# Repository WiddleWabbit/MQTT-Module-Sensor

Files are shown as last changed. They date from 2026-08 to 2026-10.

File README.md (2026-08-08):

# MQTT Module - Current Sensors

*Currently In Testing - Not Yet Tested*

This module is a plug-in board for the [MQTT Modular Controller Board](https://github.com/WiddleWabbit/MQTT-ModularControllerBoard). It powers and reads up to three 4-20mA current sensors with high-side sensing at approximately 25V, providing 15-bit resolution measurements.

## Features

- Supports up to 3 x 4-20mA sensors (high-side sensing)
- 15-bit resolution via ADS1115 ADC
- On-board ~25V boost converter from 12V input (TPS61170)
- ATmega328PB microcontroller for local control and communication
- Precision 0.1% shunt resistors with low temperature coefficient (25ppm/°C)
- Basic short-circuit protection using PTCs and TVS diodes
- I2C communication with motherboard and internal ADC

## Architecture

The module is built around an **ATmega328PB-A** microcontroller. It interfaces with the motherboard via I2C (SDA on PE1, SCL on PE0) and uses a dedicated I2C bus for the **ADS1115** ADC (base address 0x48, SDA on PC4, SCL on PC5).

### Power
- Utilises 12V input from motherboard, boosted to ~25V using TI TPS61170 (WEBENCH design) with shielded inductor for reduced EMI
- Powers up to three 4-20mA sensors using this 25V.
- Also utilises the 3.3V from the motherboard.
- Maximum 25V current draw should be less than 200mA.
- Maximum 3.3V current draw should be less than 200mA.

### Sensor Interface
- TP5551 OpAmps in servo configuration for accurate current-to-voltage conversion
- 1.5uF capacitors for signal smoothing
- 0.1% precision shunt resistors with a low 25ppm/°C

### Protection
- PTC resettable fuses on sensors trigger at ~150mA
- TVS diodes for overvoltage clamping (trigger at 13V, clamp to 21.5V)
- Shunt rated for 21.5V for five seconds

### Pinout and Connections
- **Motherboard I2C**: SDA (PE1), SCL (PE0)
- **Internal ADC I2C**: SDA (PC4), SCL (PC5)
- **SNS pin** (motherboard sense): PD4
- **General use modular pin**: PD3
- **ISP Programming Header** (2x3, left to right, top to bottom): MISO, VCC, SCK, MOSI, RESET, GND

## Setup and Build

**Firmware**: Not yet implemented. TBA.

**Programming**:
1. Use the 2x3 ISP header to program the ATmega328PB.
2. Connect to an ISP programmer (e.g., USBasp or Arduino as ISP).
3. Firmware will handle sensor readings, ADC configuration, and I2C communication with the motherboard.

**Assembly**:
- Populate the board per the KiCad project files.
- Ensure proper orientation when plugging into the motherboard slots.

## License

This documentation is part of MQTT-Module-Sensor Project and is licensed under the CERN Open Hardware Licence Version 2 - Permissive (CERN-OHL-P-2.0). 
You may redistribute and modify this documentation under the terms of the CERN-OHL-P-2.0. 
This documentation is distributed WITHOUT ANY EXPRESS OR IMPLIED WARRANTY, INCLUDING OF MERCHANTABILITY, SATISFACTORY QUALITY AND FITNESS FOR A PARTICULAR PURPOSE. See the CERN-OHL-P-2.0 for applicable conditions.

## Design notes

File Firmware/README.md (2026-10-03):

# Sensor module firmware

How the firmware runs, and the lookup pages, are in [docs/home.md](docs/home.md).

# Getting Started 

```pio run -e fuses_bootloader -t fuses```
Burn the fuses

```pio run -e Upload_ISP -t upload```
Upload

# AVR Dude

### Burning Fuses

#### Clock Speed

Use this command to read the current fuses.
```avrdude -C "%USERPROFILE%\.platformio\packages\tool-avrdude\avrdude.conf" -p atmega328pb -P COM3 -b 19200 -c stk500v1 -v -U lfuse:r:-:h -U hfuse:r:-:h -U efuse:r:-:h```

Use this command to write the fuses
```avrdude -C "%USERPROFILE%\.platformio\packages\tool-avrdude\avrdude.conf" -p atmega328pb -P COM3 -b 19200 -c stk500v1 -U lfuse:w:0xE2:m```

0xE2 Should be 11100010, which should set flag 7 (CKDIV8) to 0, stopping the device dividing the system block by 8. This may need to be modified based on what is read, hence the read command first.

#### Brown Out Detection

Use this command to read the fuse.
```avrdude -c stk500v1 -P COM3 -b 19200 -p m328pb -U efuse:r:-:h```

Use this command to write the fuse to 3.3V board (2.7V Brown Out Detection).
```avrdude -c stk500v1 -P COM3 -b 19200 -p m328pb -U efuse:w:0xFD:m```

Needs to be read in firmware and cleared as required. Holds the device in reset if it runs out of power.

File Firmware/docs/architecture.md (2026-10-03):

# Firmware architecture

[Home](home.md) · Reference: [Architecture](reference/architecture.md)

## Summary

This firmware runs on the ATmega328PB sensor daughterboard. The ESP32
motherboard is the I2C master on TWI1. This board is the master on
TWI0, where it reads three 4-20 mA inputs through an ADS1115. Plugging
it in is enough for the motherboard to assign an address and identify
a sensor module with three inputs.

`src/main.cpp` is the composition root. It owns the pin constants and
the product settings, constructs the adapters, the scan, and the link,
and calls `update()` on the scan and the link.

## Where it sits

Global construction runs before `setup()`. `ModuleLink` registers its
master-write handler there. The slave stays off until `loop()` sees
MOD low.

The motherboard bus is schematic I2C0. On this chip that is TWI1,
Arduino `Wire1`. The ADC bus is schematic I2C1, TWI0 on PC4 and PC5,
Arduino `Wire`. The ADS1115 is the only device on that bus.

## What it creates

```text
main.cpp
  AvrTwi1Slave     TWI1 adapter for IModuleSlavePort
  AvrAds1115       TWI0 adapter for IAds1115
  SensorInputs     round-robin scan and the sample cache
  ModuleLink       MOD gate, frames, and replies
```

`main.cpp` passes `MODULE_TYPE` and `FIRMWARE_VERSION` into the link,
and passes the ADS1115 address, gain, rate, input count, and connected
threshold into the scan. Pin numbers stay in `main.cpp`.

`lib/Interfaces/` holds `IModuleSlavePort` and the copied
`ModuleProtocol.h`. `lib/Drivers/` holds the AVR adapter. `lib/Logic/`
holds the link. Desktop fakes live in `test/test_desktop/fakes/`.

## One update

`setup()` drives `SNS_PIN` low so the motherboard sense line says the
module is seated, and holds `MOD_PIN` as an input with pull-up.

```mermaid
flowchart TD
  loop["loop()"] --> scan["sensorInputs.update()"]
  scan --> read["digitalRead MOD_PIN"]
  read --> upd["moduleLink.update(modIsLow)"]
```

`loop()` does not block, so a low MOD is seen inside `kModGateMaxMs`.
Each sensor pass makes one ADC-driver call and returns. While the
module has no address, MOD low enables `0x0A` and MOD high disables
it. After a valid `SET_ADDRESS`, the link keeps that address when MOD
rises.

## What is stored, and who reads it

Each pass reads `MOD_PIN` and passes that level to the link. The
motherboard reads the sense line, which `SNS_PIN` holds low.

The link stores the address and whether it has been assigned. The TWI1
adapter stores the reply the host clocks out. The scan stores the
latest ADS1115 counts. Those stores are on the
[module link](module-link.md), [sensor inputs](sensor-inputs.md),
[slave port](slave-port.md), and [ADC port](adc-port.md) pages.

## See also

- [Architecture reference](reference/architecture.md) — pins, the pass, the image build.
- [Module link](module-link.md)
- [Sensor inputs](sensor-inputs.md)
- [Slave port](slave-port.md)
- [ADC port](adc-port.md)

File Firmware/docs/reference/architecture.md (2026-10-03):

# Architecture reference

[Home](../home.md) · Guide: [Architecture](../architecture.md)

## Purpose

`src/main.cpp` wires this daughterboard. It owns the pins and the
product settings, constructs the adapters, the scan, and the link, and
calls the scan and the link once per pass.

## Classes

`setup` drives `SNS_PIN` and configures `MOD_PIN`. `loop` calls
`SensorInputs::update`, reads `MOD_PIN`, and calls `ModuleLink::update`.
The objects are `moduleSlave` (`AvrTwi1Slave`), `ads` (`AvrAds1115`),
`sensorInputs` (`SensorInputs`), and `moduleLink` (`ModuleLink`).

## States

The sketch has no mode of its own. Listening, assignment, and replies
are the link's states, on the [module link reference](module-link.md).
The scan's phases are on the
[sensor inputs reference](sensor-inputs.md).

## Sequences

1. Construction registers the master-write handler. The slave stays off.
2. `setup` sets `SNS_PIN` as an output driven low, and `MOD_PIN` as an input with pull-up.
3. Each `loop` advances the scan one driver call, reads `MOD_PIN`, and calls the link. Both calls return without waiting.

The host holds MOD low for `kModGateMaxMs` (5 ms). Because `loop` does
not block, the unconfigured address is enabled on the pass that sees
MOD low.

## Errors

Protocol status bytes come from the link. A handler that runs in the
TWI interrupt finishes inside `kClockStretchMaxMs` (40 ms). Both limits
are in `ModuleProtocol.h`.

## Configuration

Declared in `src/main.cpp`.

| Constant | Value | Port | Role |
| --- | --- | --- | --- |
| `SCL_PIN` | 23 | PE0 | Motherboard SCL, TWI1 |
| `SDA_PIN` | 24 | PE1 | Motherboard SDA, TWI1 |
| `MOD_PIN` | 3 | PD3 | Enumeration select, input pull-up |
| `SNS_PIN` | 4 | PD4 | Seated detect, driven low |
| `ADC_SDA_PIN` | 18 | PC4 | ADS1115 SDA, TWI0. `Wire` takes no pin argument |
| `ADC_SCL_PIN` | 19 | PC5 | ADS1115 SCL, TWI0. `Wire` takes no pin argument |
| `MODULE_TYPE` | `kTypeSensorModule` | | Reported by `GET_IDENTITY` |
| `FIRMWARE_VERSION` | 1 | | Reported by `GET_IDENTITY` |
| `ADS1115_ADDRESS` | `0x48` | | ADDR strapped to GND |
| `SENSOR_COUNT` | 3 | | Inputs reported by `GET_SENSOR_COUNT` |
| `SENSOR_CONNECTED_MIN_COUNTS` | 2400 | | Connected at or above this raw count |

`ads` is constructed with `AvrAds1115::kGainOne` (`0x0200`, ±4.096 V)
and `AvrAds1115::kRate860Sps` (`0x00E0`).

`kTypeSensorModule` is `0x0200` in `ModuleProtocol.h`. MiniCore's names
for the TWI1 pins are reversed. That constraint is on the
[slave port reference](slave-port.md).

The image is an ATmega328PB at 8 MHz from the internal oscillator.
`Upload_ISP` programs it with stk500v1 at 19200 on COM3.
`fuses_bootloader` sets no bootloader, brown-out 2.7 V, and EEPROM
save. The avrdude lines are in the firmware `README.md`.

## Tests

Desktop cases and the command that runs them are on the
[module link reference](module-link.md) and the
[sensor inputs reference](sensor-inputs.md).

The image build is:

```text
pio run -e Upload_ISP
```

That environment does not run the desktop tests. The TWI interrupt
path and the ADS1115 bus are not executed on the desktop.

## Source

- `src/main.cpp`
- `platformio.ini`

Sources in a library root are compiled when one of its headers is
included. `platformio.ini` does not list `lib_deps` for that reason.

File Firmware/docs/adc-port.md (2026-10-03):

# ADC port

[Home](home.md) · Reference: [ADC port](reference/adc-port.md)

## Summary

`IAds1115` is the seam between the sensor scan and the ADS1115.
`AvrAds1115` is the TWI0 adapter. It uses the Adafruit ADS1X15 library
on `Wire`. Desktop tests use `FakeAds1115`.

## Where it sits

`main.cpp` constructs `AvrAds1115` with `ADS1115_ADDRESS`,
`AvrAds1115::kGainOne`, and `AvrAds1115::kRate860Sps`, and passes it to
`SensorInputs`. The sketch does not call the driver. `SensorInputs`
does.

## What it creates

```text
IAds1115
  AvrAds1115      Adafruit ADS1115 on Wire, TWI0
  FakeAds1115     records calls and returns scripted counts
```

One driver instance owns the chip. The Adafruit object is created on
the first `begin()`, inside the driver translation unit.

## One update

The sketch does not call the driver. One scan step is one of these
calls.

```text
begin()              Wire.begin(), then probe the address
startSingleEnded()   single-shot conversion on one input
conversionReady()    read the OS bit
readCounts()         read the conversion register
```

## What is stored, and who reads it

The driver stores the address, the gain, the data rate, and whether
`begin()` succeeded. The conversion result lives in the ADS1115 until
`readCounts()`. `SensorInputs` copies it into the cache.

`ADC_SDA_PIN` and `ADC_SCL_PIN` name PC4 and PC5. `Wire` takes no pin
argument, because TWI0's pins are fixed.

## See also

- [ADC port reference](reference/adc-port.md) — gain, the OS bit, what the fake records.
- [Sensor inputs](sensor-inputs.md)
- [Architecture](architecture.md)

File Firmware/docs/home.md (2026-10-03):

# Sensor module firmware

The sensor daughter is one module. `src/main.cpp` constructs the two
bus adapters, the sensor scan, and the link. It calls `update()` on
the scan and on the link. It does not run the steps inside either one.

## How the firmware runs

Each of these is a short page: what that part creates, and what one
pass does.

1. [Architecture](architecture.md) — the loop, and who owns whom.
2. [Module link](module-link.md) — the MOD gate, then one master write.
3. [Sensor inputs](sensor-inputs.md) — one ADS1115 step, then the cache.
4. [Slave port](slave-port.md) — TWI1 on the AVR, and the desktop fake.
5. [ADC port](adc-port.md) — TWI0 to the ADS1115, and the desktop fake.

## When you need a byte, a state, or a test

The [reference index](reference/index.md) is the lookup. Each page
there has the states, the sequences, the errors, and the desktop test
that covers them.

## Wire contract

`lib/Interfaces/ModuleProtocol.h` is the copy of the motherboard
header. Frame layout, CRC-8/SMBus, command bytes, `kModGateMaxMs`, and
`kClockStretchMaxMs` live there. If a page in this tree and that header
disagree, the header wins. Change the motherboard header, then copy it
here.

This tree documents the slave. The motherboard's master sequences stay
in the motherboard firmware.

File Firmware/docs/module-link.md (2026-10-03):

# Module link

[Home](home.md) · Reference: [Module link](reference/module-link.md)

## Summary

`ModuleLink` is the slave side of the motherboard module protocol for
this sensor board. It listens at `0x0A` only while MOD is low, then
keeps the assigned address. It reports the type and firmware version
supplied at construction, protocol version 1, and the sensor count and
samples held by `SensorInputs`.

The module includes no Arduino headers.

## Where it sits

`main.cpp` constructs it with `AvrTwi1Slave`, `SensorInputs`,
`MODULE_TYPE` (`kTypeSensorModule`), and `FIRMWARE_VERSION`. `loop()`
calls `update(modIsLow)`. A master write arrives through the handler
the constructor registered, from the TWI receive callback or from
`FakeModuleSlavePort::deliver`.

## What it creates

```text
ModuleLink
  IModuleSlavePort    enable, disable, setAddress, setReply
  SensorInputs        count, connected flag, raw counts
```

The link has no submodules. It cannot be copied: the port stores the
link as the write context. The link reads the sensor cache. It does
not advance the scan.

## One update

```mermaid
flowchart TD
  upd["update(modIsLow)"] --> assigned{"assigned?"}
  assigned -->|yes| keep["leave the port as it is"]
  assigned -->|no| low{"modIsLow?"}
  low -->|yes| en["enable 0x0A if it is off"]
  low -->|no| dis["disable if it is on"]
```

A master write is a separate path. The port calls the handler from the
TWI interrupt, or the fake calls it from `deliver`. Commands, rejects,
and the padded reply are in the [reference](reference/module-link.md).

## What is stored, and who reads it

`_typeId` and `_firmwareVersion` come from the constructor.
`GET_IDENTITY` reads them. `GET_SENSOR_COUNT`, `GET_SENSOR_CONNECTED`,
and `GET_SENSOR_READING` read the `SensorInputs` cache.

`_address` starts at `kUnconfiguredAddress`. `update` enables that
address while MOD is low. An accepted `SET_ADDRESS` replaces it and
sets `_assigned`. `_enabled` records whether the port is listening.
Once `_assigned` is set, `update` leaves the port alone.

The link does not keep the last reply. `setReply` copies it into the
port before the handler returns. The host reads that copy.

## See also

- [Module link reference](reference/module-link.md) — states, commands, errors, tests.
- [Sensor inputs](sensor-inputs.md)
- [Slave port](slave-port.md)
- [Architecture](architecture.md)

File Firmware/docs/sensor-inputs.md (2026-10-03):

# Sensor inputs

[Home](home.md) · Reference: [Sensor inputs](reference/sensor-inputs.md)

## Summary

`SensorInputs` scans the ADS1115 and keeps the latest counts for each
input. `ModuleLink` reads that cache when the motherboard asks for a
count, a presence, or a reading. The scan runs from `loop()`. The TWI1
handler does not talk to the ADC.

## Where it sits

`main.cpp` constructs it with `AvrAds1115`, `SENSOR_COUNT`, and
`SENSOR_CONNECTED_MIN_COUNTS`. `loop()` calls `update()` and then
`moduleLink.update()`. The link does not call `update()`.

## What it creates

```text
SensorInputs
  IAds1115    begin, start, poll, read
```

On this board the count is 3. Index 0 is Sens1 on AIN0, index 1 is
Sens2 on AIN1, and index 2 is Sens3 on AIN2. AIN3 is unconnected.

## One update

```mermaid
flowchart TD
  upd["update()"] --> none{"count is 0?"}
  none -->|yes| stop["return"]
  none -->|no| begun{"begun?"}
  begun -->|no| begin["begin() and return"]
  begun -->|yes| st{"phase?"}
  st -->|Starting| start["startSingleEnded(channel)"]
  st -->|Waiting| rdy{"conversionReady()?"}
  rdy -->|no| wait["return"]
  rdy -->|yes| mark["remember that the result is ready"]
  st -->|Reading| store["store counts and the connected flag"]
  store --> next["next channel, then Starting"]
```

One `update()` makes one driver call. The first sample is a begin, a
start, a ready poll, and a read. Each later sample is a start, a poll,
and a read.

## What is stored, and who reads it

The constructor stores the count and the connected threshold.
`update()` stores the latest counts and a connected flag for each
input. The flag is set when the counts are at or above
`SENSOR_CONNECTED_MIN_COUNTS`.

The valid flag for that input is cleared before those bytes are
written and set after them. `ModuleLink` reads an input from the TWI1
handler only while its flag is set. Until the first stored conversion,
the link replies `Busy`.

## See also

- [Sensor inputs reference](reference/sensor-inputs.md) — phases, the threshold, tests.
- [ADC port](adc-port.md)
- [Module link](module-link.md)
- [Architecture](architecture.md)

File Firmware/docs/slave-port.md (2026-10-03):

# Slave port

[Home](home.md) · Reference: [Slave port](reference/slave-port.md)

## Summary

`IModuleSlavePort` is the seam between the link and the bus.
`AvrTwi1Slave` is the TWI1 adapter. Desktop tests use
`FakeModuleSlavePort`. The fake's `deliver` calls the same handler the
driver's receive callback calls.

## Where it sits

`main.cpp` constructs `AvrTwi1Slave` and passes it to `ModuleLink`. The
link calls `enable`, `disable`, `setAddress`, and `setReply`. The
driver calls the link back on a master write. Tests construct the fake
in place of the driver.

## What it creates

```text
IModuleSlavePort
  AvrTwi1Slave          Wire1 on TWI1
  FakeModuleSlavePort   records calls
```

Wire's callbacks are plain function pointers, so one driver instance
is the active slave. That instance attaches one protocol handler.

## One update

The sketch does not call the driver. One transaction is a master
write, then the repeated-start read.

```mermaid
flowchart TD
  rx["onReceive"] --> hand["write handler"]
  hand --> reply["setReply copies the frame"]
  reply --> tx["onRequest clocks the copy out"]
```

`setAddress` writes `TWAR1` from the stop callback and leaves the bus
up. `disable` calls `Wire1.end()`.

## What is stored, and who reads it

The driver keeps the handler, the reply bytes, and whether TWI1 is
enabled. The host clocks the reply out on the next read. `TWAR1` is
the address the peripheral acknowledges. The fake keeps the same calls
so a test can read them.

`SCL_PIN` and `SDA_PIN` name the motherboard-bus pins. `Wire1` takes
no pin argument, because TWI1's pins are fixed.

## See also

- [Slave port reference](reference/slave-port.md) — `TWAR1`, pin names, what the fake records.
- [Module link](module-link.md)
- [Architecture](architecture.md)

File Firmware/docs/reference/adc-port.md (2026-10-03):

# ADC port reference

[Home](../home.md) · Guide: [ADC port](../adc-port.md)

## Purpose

One ADC port, two adapters. The scan starts a conversion, polls it,
and reads the counts. `AvrAds1115` does that on TWI0 through Adafruit
ADS1X15. `FakeAds1115` records the same calls.

## Classes

`IAds1115`:

| Method | Role |
| --- | --- |
| `begin()` | Start the bus and probe the chip |
| `startSingleEnded(channel)` | Start one single-shot conversion. Channel 0 is AIN0 |
| `conversionReady()` | True when the OS bit says the conversion is done |
| `readCounts()` | Signed result of the last conversion |

`AvrAds1115(address7bit, gain, dataRate)` stores those settings and
leaves the bus idle. `kGainOne` is `0x0200` (±4.096 V, 125 uV per
count). `kRate860Sps` is `0x00E0`. Copy and assignment are deleted.

`FakeAds1115` records `begin`, `startSingleEnded`, `conversionReady`,
and `readCounts`. `readCounts` returns `counts[lastChannel]`.

## States

The driver starts with the bus idle. `begin()` sets the gain and the
data rate, calls `Wire.begin()`, and probes the address. A gain other
than `kGainOne`, or a rate other than `kRate860Sps`, returns false and
does not mark the bus ready. Later calls return false, or 0 counts,
until a `begin()` succeeds.

## Sequences

`startSingleEnded` rejects a channel above 3. Adafruit's
`startADCReading` writes the config register and both threshold
registers. The threshold writes arm ALERT/RDY. That pin is
unconnected on this board. `conversionReady()` polls the config
register OS bit.

`Wire.begin()` turns on the internal pull-ups on PC4 and PC5, in
parallel with the board's pull-ups. `ADC_SDA_PIN` is 18 and
`ADC_SCL_PIN` is 19. `Wire` takes no pin arguments.

The ADS1115 address is `ADS1115_ADDRESS` (`0x48`). ADDR is strapped
to GND.

## Errors

`begin()` false means the chip did not acknowledge, or the gain or
rate was refused. `startSingleEnded` false means the bus is not ready
or the channel is above 3. `readCounts()` before a successful `begin()`
returns 0.

Adafruit's start and register reads do not report a bus error of
their own. A chip that stops acknowledging after `begin()` leaves
`conversionReady()` false, so the scan stays on that channel.

## Configuration

Passed from `main.cpp`: address `0x48`, `kGainOne`, `kRate860Sps`.
Single-ended readings use the positive half of the code, 0..32767.
The connected threshold is a `SensorInputs` setting, on the
[sensor inputs reference](sensor-inputs.md).

## Tests

There is no separate driver test. The sensor-input tests drive
`FakeAds1115`. The cases are on the
[sensor inputs reference](sensor-inputs.md). The TWI0 path is not
executed on the desktop. `pio run -e Upload_ISP` compiles
`AvrAds1115`.

## Source

- `lib/Interfaces/IAds1115.h`
- `lib/Drivers/AvrAds1115.h`
- `lib/Drivers/AvrAds1115.cpp`
- `test/test_desktop/fakes/FakeAds1115.h`

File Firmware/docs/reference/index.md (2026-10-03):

# Reference

[Home](../home.md)

These pages are the lookup: states, bytes, errors, and the desktop
test that covers them. The short pages one level up say who creates
what and what one pass does.

- [Architecture](architecture.md) — pins, the pass, and the image build.
- [Module link](module-link.md) — MOD gate, commands, and the desktop tests.
- [Sensor inputs](sensor-inputs.md) — the scan, the cache, and the threshold.
- [Slave port](slave-port.md) — TWI1, `TWAR1`, and the fake.
- [ADC port](adc-port.md) — TWI0, GAIN_ONE, and the fake.

The wire constants are `lib/Interfaces/ModuleProtocol.h`. Master
sequences are not in this tree.

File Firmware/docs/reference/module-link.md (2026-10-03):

# Module link reference

[Home](../home.md) · Guide: [Module link](../module-link.md)

## Purpose

Slave side of the module protocol for one sensor module. It accepts an
address while MOD is low, then identifies as the type and firmware
version it was given, with protocol version 1. Sensor commands read
the `SensorInputs` cache.

Frame layout, CRC-8/SMBus, and command bytes are in
`lib/Interfaces/ModuleProtocol.h`. If this page and that header
disagree, the header wins.

## Classes

`ModuleLink(IModuleSlavePort& port, SensorInputs& sensors, uint16_t typeId, uint16_t firmwareVersion)`
binds the port and the sensor cache, and registers the master-write
handler. The slave stays off. Copy and assignment are deleted.

`update(bool modIsLow)` is the call `loop` makes.

The port methods the link uses are `enable`, `disable`, `setAddress`,
`setReply`, and `setMasterWriteHandler`. `setReply` copies the bytes
before it returns.

## States

`kUnconfiguredAddress` is `0x0A`.

```text
boot, MOD high          slave off; stored address is 0x0A
MOD low                 enable 0x0A once
MOD low again           no second enable
MOD high, no address    disable once
SET_ADDRESS accepted    setAddress(new); stay enabled; assigned
MOD high after that     stay enabled at the new address
```

## Sequences

A master write is checked in this order:

1. A null buffer, or fewer than `kMinFrameBytes` (3), replies `BadLength`.
2. The length byte must be from 2 through `2 + kMaxPayload`, and the
   buffer size must be that length plus one. Otherwise `BadLength`.
3. CRC-8/SMBus over the bytes the length covers must match the CRC
   byte. Otherwise `BadCrc`, and the address stays as it is.
4. The command runs.

A reply is `kMaxFrameBytes` (19) long. The real frame comes first. The
rest is `0xFF`. `SET_ADDRESS`, accepted or refused as an address, queues
no reply.

On the AVR the handler runs from the TWI interrupt. On the desktop,
`FakeModuleSlavePort::deliver` calls it. It finishes inside
`kClockStretchMaxMs`.

## Commands

| Command | When | Result |
| --- | --- | --- |
| `PING` | empty payload | status `Ok`, empty payload |
| `PING` | any payload | `BadLength` |
| `GET_IDENTITY` | empty payload | type, protocol 1, firmware version |
| `GET_IDENTITY` | any payload | `BadLength` |
| `SET_ADDRESS` | enabled, not yet assigned, one payload byte, address `0x10`–`0x6F` | `setAddress`, no reply |
| `SET_ADDRESS` | payload length is not 1 | `BadLength`, no commit |
| `SET_ADDRESS` | disabled, already assigned, or address outside `0x10`–`0x6F` | no reply, no commit |
| `GET_SENSOR_COUNT` | empty payload | status `Ok`, the cache's count |
| `GET_SENSOR_COUNT` | any payload | `BadLength` |
| `GET_SENSOR_CONNECTED` | one index byte, index inside the count, sample stored | `Ok`, index, connected `0` or `1` |
| `GET_SENSOR_READING` | one index byte, index inside the count, sample stored | `Ok`, index, connected, raw counts as big-endian `int32` |
| `GET_SENSOR_CONNECTED`, `GET_SENSOR_READING` | index inside the count, no sample yet | `Busy` |
| `GET_SENSOR_CONNECTED`, `GET_SENSOR_READING` | payload length is not 1, or index at or above the count | `BadLength` |
| any other command, including `ECHO` | | `UnknownCmd` |

Identity payload, big-endian: type high, type low, `kProtocolVersion`,
firmware high, firmware low. `kIdentityPayloadLen` is 5.

`SET_ADDRESS` commits from the stop callback, before the motherboard
releases MOD. A later `SET_ADDRESS` is ignored. `0x00` is not an
assignable address. `isAssignableAddress` accepts `kMinAssignedAddress`
through `kMaxAssignedAddress`.

## Errors

| Status | Constant | When |
| --- | --- | --- |
| `Ok` | `kStatusOk` (`0x00`) | PING, identity, sensor count, or a stored sample |
| `BadCrc` | `kStatusBadCrc` (`0x01`) | CRC byte does not match |
| `UnknownCmd` | `kStatusUnknownCmd` (`0x02`) | Command this type does not implement |
| `BadLength` | `kStatusBadLength` (`0x03`) | Short frame, length mismatch, a payload length the command rejects, or a sensor index outside the count |
| `Busy` | `kStatusBusy` (`0x04`) | Presence or reading for an input that has no stored sample yet |

A refused `SET_ADDRESS` leaves the address in place and queues no
status. The header also defines `Unsupported`. This link does not send
it. The reading payload is `kSensorReadingPayloadLen` (6): index,
connected, then the raw counts. The connected payload is
`kSensorConnectedPayloadLen` (2): index, then 0 or 1. The count
payload is one byte.

## Configuration

`typeId` and `firmwareVersion` are constructor arguments. The sketch
passes `MODULE_TYPE` and `FIRMWARE_VERSION`, listed on the
[architecture reference](architecture.md). `GET_IDENTITY` reports the
values it was given.

The sensor count, the connected threshold, and the raw counts come
from `SensorInputs`. The sketch passes `SENSOR_COUNT` and
`SENSOR_CONNECTED_MIN_COUNTS` into that object. The value on the wire
is the ADS1115 code, not a scaled current.

## Tests

`test/test_desktop/test_module_link.cpp` drives `FakeModuleSlavePort`.

| Test | Path |
| --- | --- |
| `testBootWithModHighLeavesSlaveDisabled` | MOD high at boot leaves the slave off |
| `testModLowEnablesUnconfiguredAddressAndModHighDisables` | `0x0A` follows MOD until assignment; a second call does not enable or disable again |
| `testPingReplyIsOkAndPadded` | `Ok` PING, CRC, 19-byte `0xFF` pad |
| `testIdentityReportsSensorModule` | Type `0x0200`, protocol 1, firmware 1 |
| `testSuppliedFirmwareVersion` | Identity uses the constructor values (`0x1234`, firmware 2) |
| `testSetAddressCommitsAndSurvivesModHigh` | A write while off does not commit. Then commit `0x10`, ignore `0x11`, stay on after MOD rises, and still answer PING |
| `testSetAddressRejectsBadCrcAndIllegalAddresses` | Bad CRC, `0x00`, `0x0A`, and `0x70` stay at `0x0A` |
| `testSensorCommandsReportCachedReadings` | Count 3. `Busy` before a sample. 2399 is disconnected, 2400 is connected, and -4 is disconnected. Channel 0 still reads 2399 after the others are stored |
| `testSensorCommandsRejectBadIndexAndLength` | Index 3, a short or long reading payload, a count payload, and index 0 on a count of 0 are `BadLength` |
| `testUnknownCommandAndMalformedFrames` | `ECHO`, truncated frame, extra byte, bad CRC, PING with a payload, empty `SET_ADDRESS` |
| `testEnumerationSequence` | PING, assign `0x12`, MOD high, identity, count 3 |

```text
C:\Users\Nathan\.platformio\penv\Scripts\platformio.exe test -e native
```

## Source

- `lib/Logic/ModuleLink.h`
- `lib/Logic/ModuleLink.cpp`
- `test/test_desktop/test_module_link.cpp`
- `test/test_desktop/fakes/FakeModuleSlavePort.h`

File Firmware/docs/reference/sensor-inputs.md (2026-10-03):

# Sensor inputs reference

[Home](../home.md) · Guide: [Sensor inputs](../sensor-inputs.md)

## Purpose

Scan the ADS1115 inputs and remember the latest counts. The link
reports that cache. The scan is a sequence of single driver calls so
`loop()` can still see MOD within `kModGateMaxMs`.

## Classes

`SensorInputs(IAds1115& adc, uint8_t count, int16_t connectedMinCounts)`
binds the port. Copy and assignment are deleted.

`update()` advances one step. `count()`, `hasSample(index)`,
`connected(index)`, and `counts(index)` are what the link reads. An
index outside the count has no sample, is not connected, and reads as
0 counts.

A count above `kMaxSensorsPerModule` (16) is stored as 16.

## States

```text
count 0                 update returns; the ADC is not started
not begun               the next update calls begin()
Starting                the next update calls startSingleEnded(channel)
Waiting                 the next update calls conversionReady()
Reading                 the next update calls readCounts() and stores it
```

`begin()` returning false leaves the scan not begun, so the next pass
tries again. `startSingleEnded` returning false leaves the phase at
`Starting` on the same channel. The previous sample stays. A ready
poll that is false stays in `Waiting`.

After a stored sample the channel advances by one and wraps to 0.

## Sequences

Publishing one sample clears that input's valid flag, writes the
counts and the connected flag, then sets the valid flag. The connected
flag is 1 when the signed counts are greater than or equal to
`connectedMinCounts`.

Index 0 is AIN0 (Sens1), index 1 is AIN1 (Sens2), and index 2 is AIN2
(Sens3).

## Errors

A missing chip keeps `begin()` false. No input has a sample, and the
link replies `Busy` for presence and reading. The count is still
reported.

A start that fails does not erase a sample already stored for another
input. The scan retries the channel that failed.

`counts()` for an input with no sample returns 0. The link treats
"no sample" as `Busy` rather than as a reading of 0.

## Configuration

The sketch passes `SENSOR_COUNT` (3) and
`SENSOR_CONNECTED_MIN_COUNTS` (2400). 2400 counts is 0.300 V at
GAIN_ONE, 125 uV per count, which is 2 mA through the 150 ohm shunt.
A 4 mA loop is 0.600 V, 4800 counts. A 20 mA loop is 3.000 V, 24000
counts. An open input sits near 0 V.

The gain and the sample rate are arguments to `AvrAds1115`, listed on
the [architecture reference](architecture.md).

## Tests

`test/test_desktop/test_sensor_inputs.cpp` drives `FakeAds1115`.
`test/test_desktop/test_module_link.cpp` checks the frames the link
builds from the same cache.

| Test | Path |
| --- | --- |
| `testScanStoresEachChannelThenWraps` | Channel 0, then 1, then 2, then channel 0 again. 2399 is disconnected, 2400 is connected, and a negative code stays negative. A new conversion replaces channel 0 |
| `testBeginFailureRetriesAndDoesNotStart` | `begin()` false retries and does not start a conversion |
| `testStartFailureKeepsTheLastSampleAndRetriesTheChannel` | A refused start keeps channel 0 and retries channel 1 |
| `testWaitingDoesNotReadOrAdvance` | A conversion that is not ready is polled, not read |
| `testZeroCountDoesNotTouchTheAdc` | Count 0 does not call the ADC |
| `testCountAboveProtocolMaxIsClamped` | A count of 17 is stored as 16 |
| `testSensorCommandsReportCachedReadings` | Count 3. `Busy` before a sample. Then 2399 disconnected, 2400 connected, and -4 disconnected, each on the wire |
| `testSensorCommandsRejectBadIndexAndLength` | Index 3, a short or long payload, a count payload, and index 0 when the count is 0 are `BadLength` |

```text
C:\Users\Nathan\.platformio\penv\Scripts\platformio.exe test -e native
```

## Source

- `lib/Logic/SensorInputs.h`
- `lib/Logic/SensorInputs.cpp`
- `test/test_desktop/test_sensor_inputs.cpp`
- `test/test_desktop/fakes/FakeAds1115.h`

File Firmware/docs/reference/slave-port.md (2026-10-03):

# Slave port reference

[Home](../home.md) · Guide: [Slave port](../slave-port.md)

## Purpose

One slave port, two adapters. The link enables TWI, commits an address,
and queues a reply. `AvrTwi1Slave` does that on TWI1.
`FakeModuleSlavePort` records the same calls.

## Classes

`IModuleSlavePort`:

| Method | Role |
| --- | --- |
| `enable(address7bit)` | Start listening at a 7-bit address |
| `disable()` | Stop acknowledging |
| `setAddress(address7bit)` | Commit a new address without leaving the bus |
| `setReply(frame, length)` | Copy the next reply. The pointer is valid only for this call |
| `setMasterWriteHandler(handler, context)` | One handler. A later call replaces it |

`AvrTwi1Slave` implements that on `Wire1`. `FakeModuleSlavePort`
records `enable`, `disable`, `setAddress`, and `setReply`. `deliver`
invokes the registered handler.

## States

The driver starts disabled. `enable` selects this instance, clears the
reply length, calls `Wire1.begin(address7bit)`, and registers
`onReceive` and `onRequest`. `disable` calls `Wire1.end()` and clears
the enabled flag. `setAddress` writes `TWAR1` only while enabled.

## Sequences

`setAddress` writes `TWAR1` as `address7bit << 1`. Bit 0 stays clear,
so general call stays off. The write is safe from the stop callback.
It does not call `Wire1.end()`.

`disable` stops TWI1. The pins return to inputs with the internal
pull-ups off. The motherboard's 4.7 kΩ resistors hold the bus.

`enable` turns on the internal pull-ups on both TWI1 pins, in parallel
with those resistors.

`_onReceive` reads the bytes `Wire1` has and calls the handler. A
missing instance or a missing handler returns. `_onRequest` clocks out
the stored reply. A reply length of 0 sends nothing.

MiniCore's pin header labels PE0 as `SDA1` and PE1 as `SCL1`. The TWI1
peripheral and this PCB use PE0 as SCL and PE1 as SDA. `Wire1.begin()`
still connects that peripheral. `SCL_PIN` and `SDA_PIN` in `main.cpp`
name those pins. `Wire1` takes no pin arguments.

## Errors

`setReply` with a null frame stores a length of 0, so the next read
sends nothing. A length above `kMaxFrameBytes` is stored as 19 bytes.

`setAddress` while disabled does not write `TWAR1`.

`_onReceive` passes the handler the number of bytes read from `Wire1`.
When `Wire1`'s count is larger than that, the count is the length
instead. Only the first `kMaxFrameBytes` are stored. The link then
applies its length check to that buffer.

## Configuration

The driver has no product settings. The address comes from the link:
`kUnconfiguredAddress`, then the assigned address. Pin constants are
on the [architecture reference](architecture.md).

## Tests

There is no separate driver test. The module-link tests drive
`FakeModuleSlavePort`. The cases are on the
[module link reference](module-link.md). The interrupt path is not
executed on the desktop. `pio run -e Upload_ISP` compiles
`AvrTwi1Slave`.

## Source

- `lib/Interfaces/IModuleSlavePort.h`
- `lib/Drivers/AvrTwi1Slave.h`
- `lib/Drivers/AvrTwi1Slave.cpp`
- `test/test_desktop/fakes/FakeModuleSlavePort.h`

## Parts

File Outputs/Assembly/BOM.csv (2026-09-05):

# | Qty | Reference | Value | Manufacturer | Manufacturer Part No | JLCPCB Part # | Package | Footprint
1 | 8 | C201,C202,C203,C204,C407,C502,C504,C506 | 0.1uF 10% 50V | YAGEO | CC0603KRX7R9BB104 | C14663 | 0603 | JLCPCB Basic:CAPC1608X90N
2 | 3 | C302,C303,C304 | 4.7uF 10% 25V | Samsung Electro-Mechanics | CL21A475KAQNNNE | C1779 | 0805 | JLCPCB Basic:CAPC2012X140N
3 | 1 | C307 | 4.7uF 10% 50V | FH (Guangdong Fenghua Advanced Tech) | 1206B475K500NT | C29823 | 1206 | JLCPCB Basic:CAPC3216X180N
4 | 1 | C308 | 22nF 10% 50V | Samsung Electro-Mechanics | CL21B223KBANNNC | C1729 | 0805 | JLCPCB Basic:CAPC2012X75N
5 | 1 | C309 | 10uF 20% 35V | PANASONIC | EEEFK1V100R | C336198 | SMD | PANASONIC Capacitors:EEE0GA101SR
6 | 3 | C501,C503,C505 | 1uF 10% 50V | Samsung Electro-Mechanics | CL21B105KBFNNNE | C28323 | 0805 | JLCPCB Basic:CAPC2012X135N
7 | 1 | D301 | 40V 1A | Guangdong Hottech | 1N5819WS | C191023 | SOD-323 | GUANGDONG HOTTECH Diodes:D_SOD-323F
8 | 9 | D401,D402,D403,D404,D405,D406,D407,D408,D409 | 28V 1uA Leak | Littelfuse | SMF28A | C720061 | SOD-123FL | LITTELFUSE Diodes:SODFL3619X98N
9 | 3 | F502,F503,F505 | 50mA 30V, PTC | BOURNS | MF-USMF005-2 | C118758 | 1210 | BOURNS Fuses:FUSC3226X110N
10 | 1 | IC401 | 16 Bit ADC | Texas Instruments | ADS1115IDGST | C468683 | VSSOP-10-0.5mm | TEXAS INSTRUMENTS ICs:SOP50P490X110-10N
11 | 2 | J301,J302 | A2541WV-10P | CJT(Changjiang Connectors) | A2541WV-10P | C225485 | Plugin,P=2.54mm | CJT Connectors:PinHeader_1x10_P2.54mm_Vertical_Male
12 | 1 | J303 | A2541WV-2x3P | CJT(Changjiang Connectors) | A2541WV-2x3P | C225518 | Plugin,P=2.54mm | CJT Connectors:PinHeader_2x03_P2.54mm_Vertical_Male
13 | 1 | J304 | 1715747 | Phoenix Contact | 1715747 | C5443561 | P=5.08mm | PHOENIX CONTACT Terminals:1715747
14 | 1 | L301 | 15uH, 1.25A, 20% | Vishay Intertech | IFSC1515AHER150M01 | C844950 | SMD,4x4mm | VISHAY INTERTECH Inductors:INDM4040X190N
15 | 1 | PS301 | TPS61170DRVR | Texas Instruments | TPS61170DRVR | C15163 | WSON-6(2x2) | TEXAS INSTRUMENTS ICs:SON65P200X200X80-7N
16 | 2 | R201,R304 | 10kΩ 1/8W 1% | UNI-ROYAL(Uniroyal Elec) | 0805W8F1002T5E | C17414 | 0805 | JLCPCB Basic:RESC2013X65N
17 | 1 | R301 | 24kΩ 1/8W 1% | UNI-ROYAL(Uniroyal Elec) | 0805W8F2402T5E | C17575 | 0805 | JLCPCB Basic:RESC2013X65N
18 | 1 | R303 | 200kΩ 1/8W 1% | UNI-ROYAL(Uniroyal Elec) | 0805W8F2003T5E | C17539 | 0805 | JLCPCB Basic:RESC2013X65N
19 | 2 | R401,R417 | 4.7kΩ 1/8W 1% | UNI-ROYAL(Uniroyal Elec) | 0805W8F4701T5E | C17673 | 0805 | JLCPCB Basic:RESC2013X65N
20 | 3 | R501,R506,R511 | 150Ω 0.1% 1/2W | Vishay | TNPW1206150RBEEA | C2075942 | 1206 | VISHAY INTERTECH Resistors:RESC3216X71N
21 | 12 | R502,R503,R504,R505,R507,R508,R509,R510,R512,R513,R514,R515 | 100kΩ 1/8W 1% | UNI-ROYAL(Uniroyal Elec) | 0805W8F1003T5E | C149504 | 0805 | JLCPCB Basic:RESC2013X65N
22 | 1 | U202 | ATmega328PB-A | Microchip Tech | ATMEGA328PB-AU | C132230 | TQFP-32(7x7) | Package_QFP:TQFP-32_7x7mm_P0.8mm
23 | 3 | U501,U502,U503 | Precision ZD RR | 3PEAK | TP5551-TR | C2759987 | SOT-23-5 | 3PEAK OpAmps:S5TSOT23-5-A_TPK

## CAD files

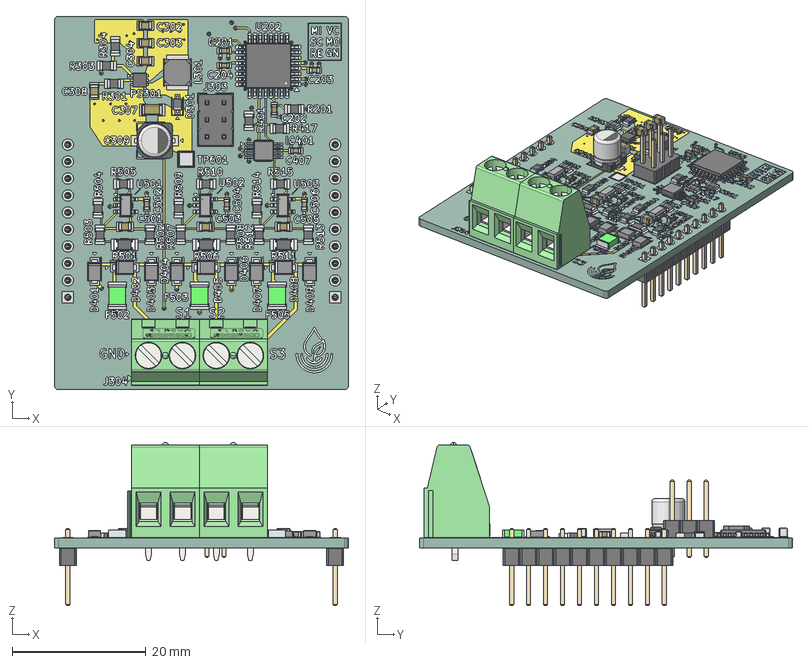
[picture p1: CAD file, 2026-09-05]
Outputs/Models/Model.step
44.0 x 55.9 x 24.4 mm
PinKIdent x 9
PinK x 9
PinA x 9
term1 x 21
term2 x 21
BODY-SON
PIN1-ID x 2
S5T_SOT23-5-A__TPK x 3
BODY-SO
LEAD-SO x 10
TQFP-32_7x7mm_P0.8mm
IFSC1515AHER150M01
TNPW1206150RBEEA x 3
PinHeader_2x03_P2.54mm_Vertical
D_SOD-323F
WSIZE CODE C-001
WSIZE CODE C-002
WSIZE CODE C-003 x 2
PinHeader_1x10_P2.54mm_Vertical x 2
MQTT-Module-CurrentSensors_copper
MQTT-Module-CurrentSensors_pad
MQTT-Module-CurrentSensors_via
MQTT-Module-CurrentSensors_silkscreen x 2
MQTT-Module-CurrentSensors_PCB

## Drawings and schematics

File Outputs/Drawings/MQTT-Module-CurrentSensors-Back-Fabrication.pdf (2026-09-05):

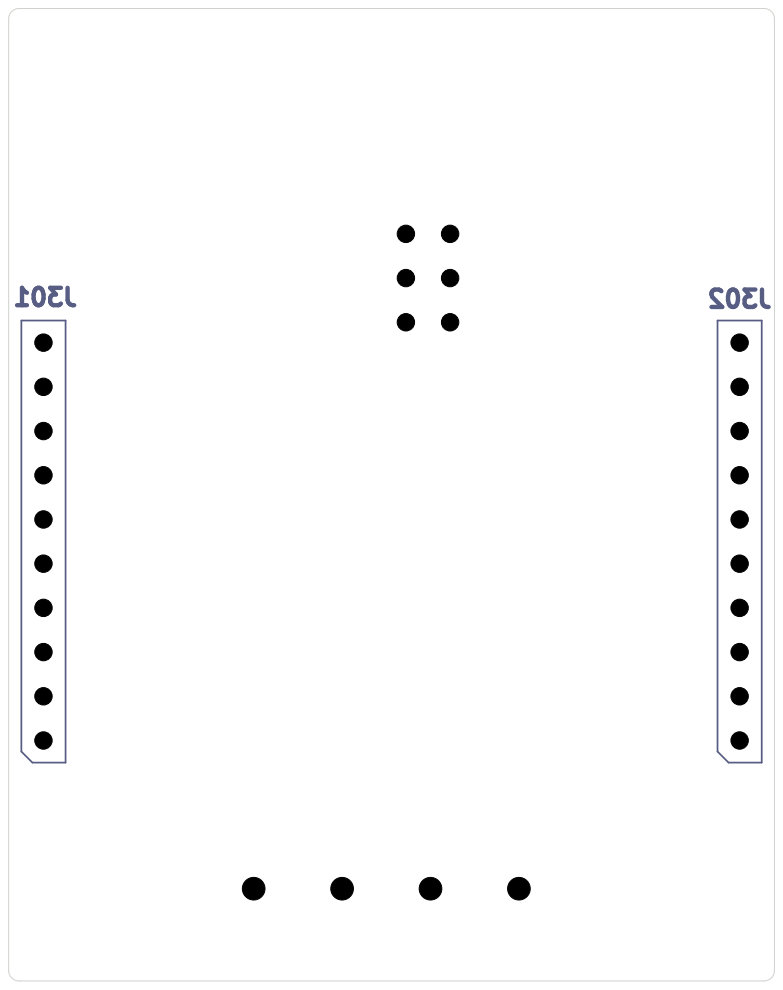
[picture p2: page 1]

Id: 1/1 Title: File: MQTT-Module-CurrentSensors.kicad_pcb Sheet:

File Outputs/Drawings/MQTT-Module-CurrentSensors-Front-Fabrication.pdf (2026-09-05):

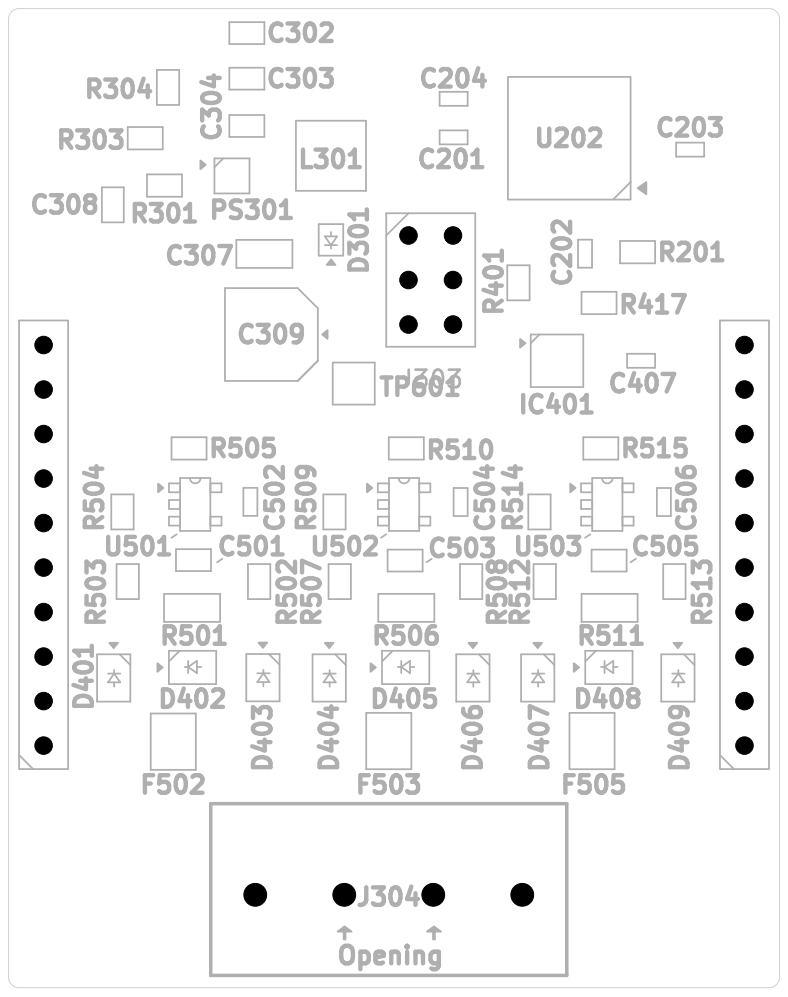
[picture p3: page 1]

Id: 1/1 Title: File: MQTT-Module-CurrentSensors.kicad_pcb Sheet:

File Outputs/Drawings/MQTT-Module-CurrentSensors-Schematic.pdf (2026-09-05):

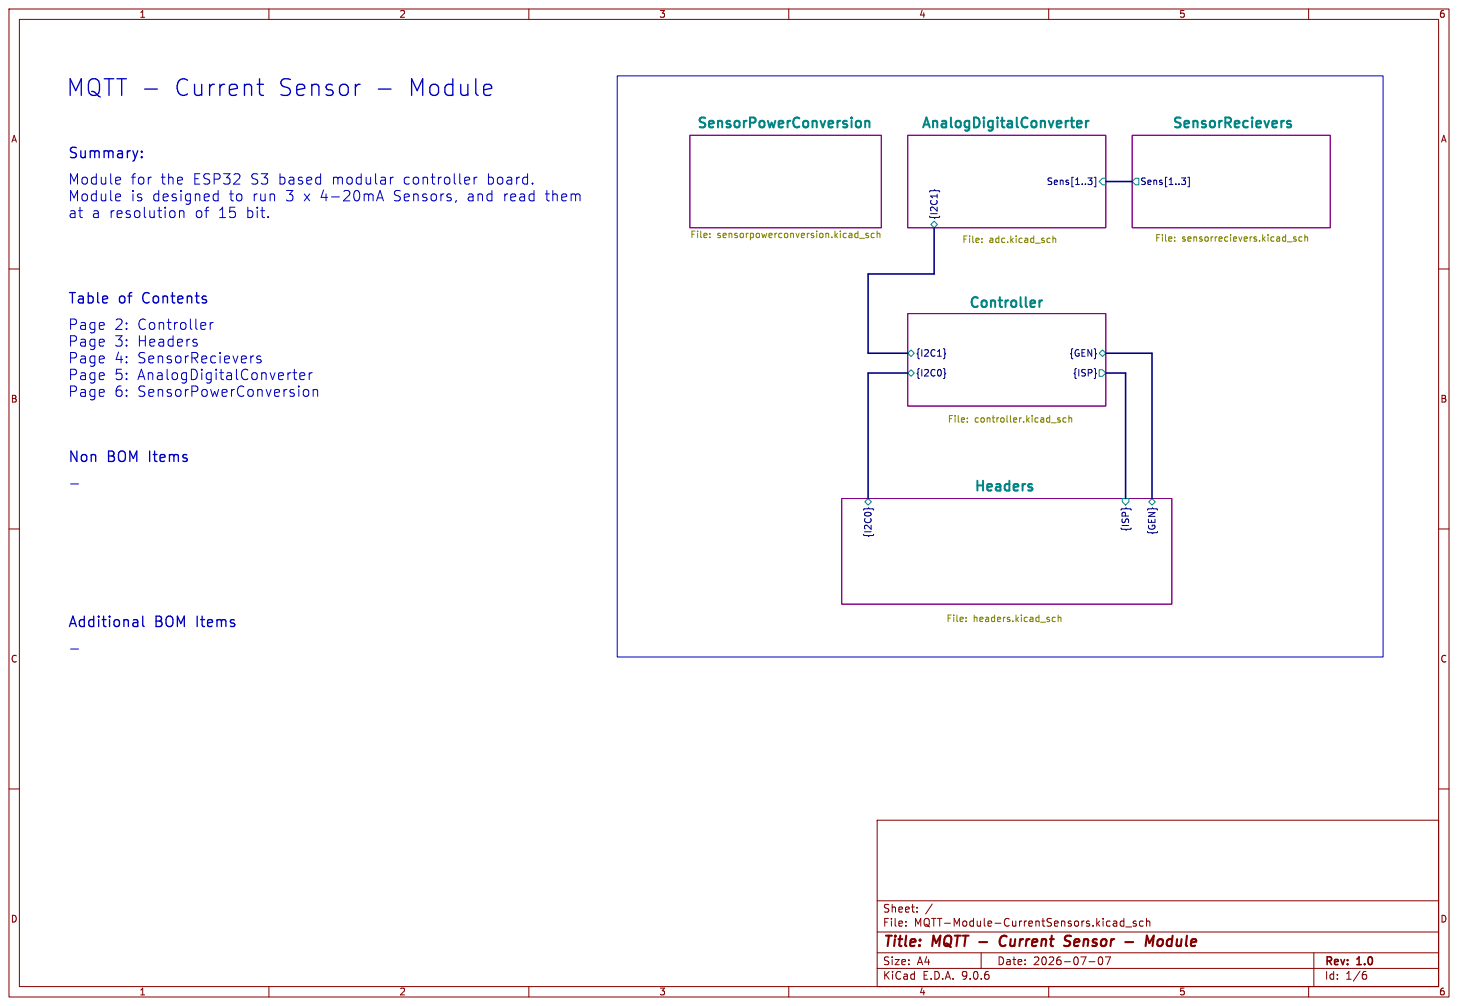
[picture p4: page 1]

MQTT - Current Sensor - Module
-Summary:

File: MQTT-Module-CurrentSensors.kicad_sch Sheet: /
Id: 1/6 Title: MQTT - Current Sensor - Module

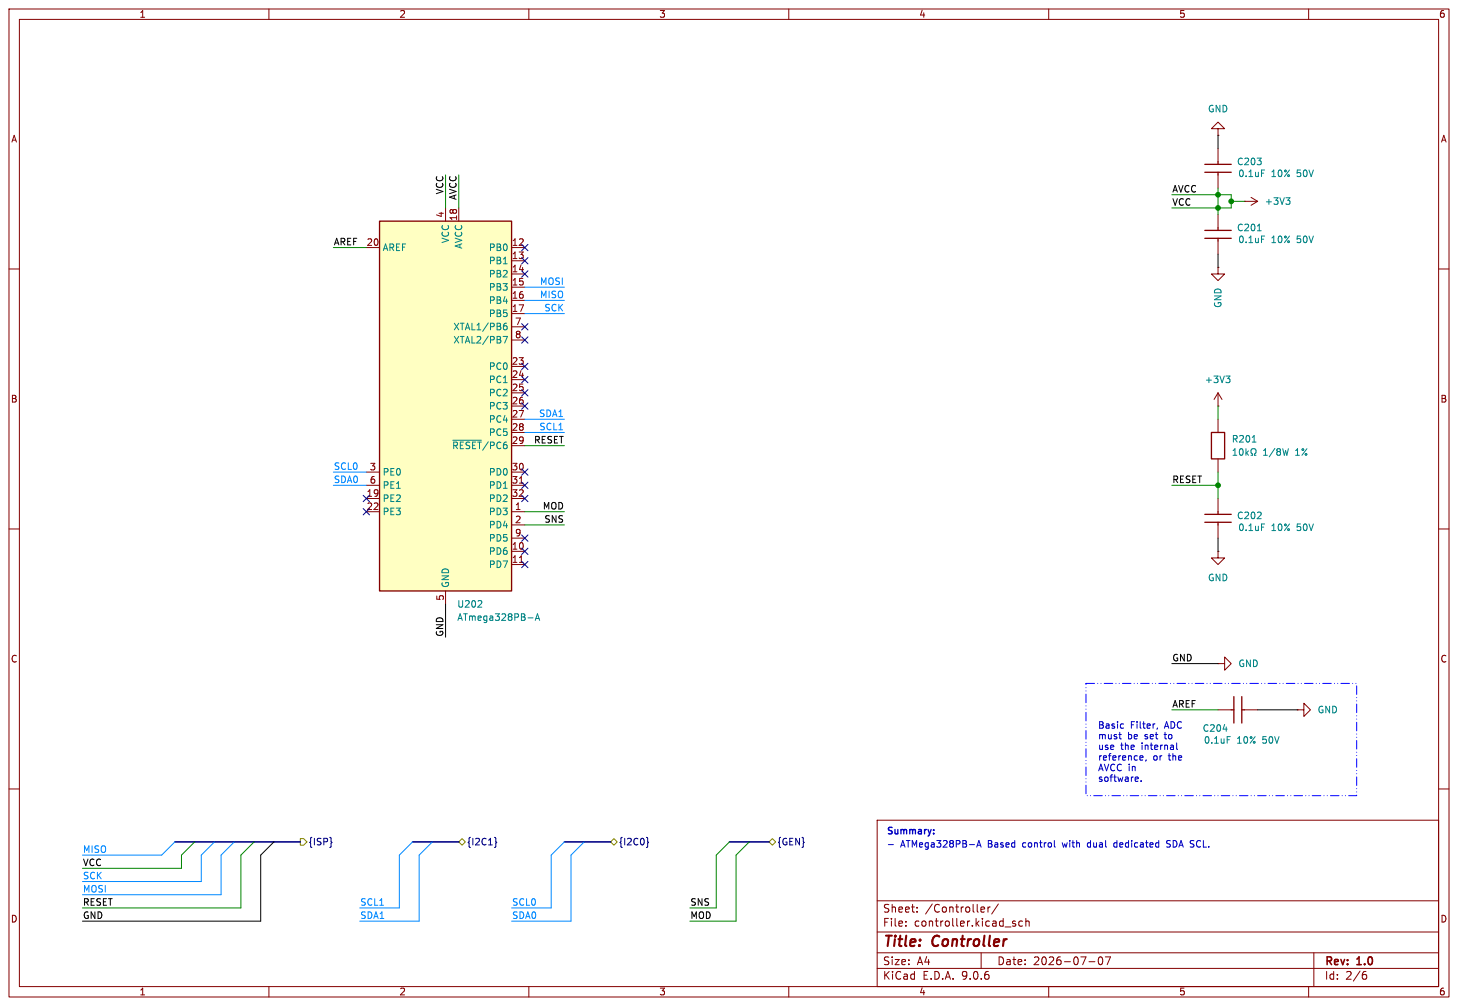
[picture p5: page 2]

Basic Filter, ADC must be set to

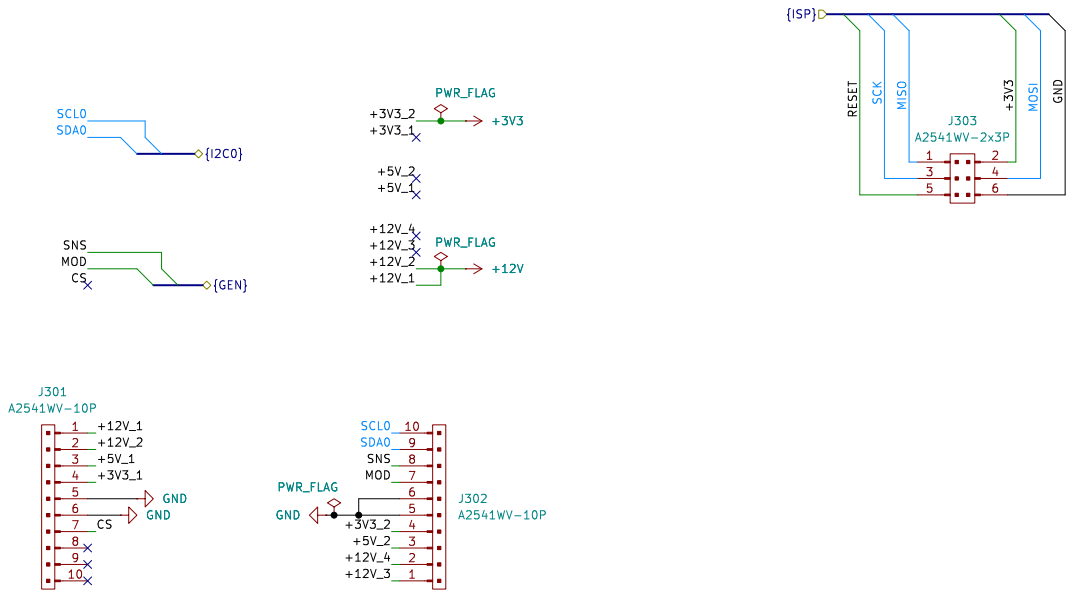
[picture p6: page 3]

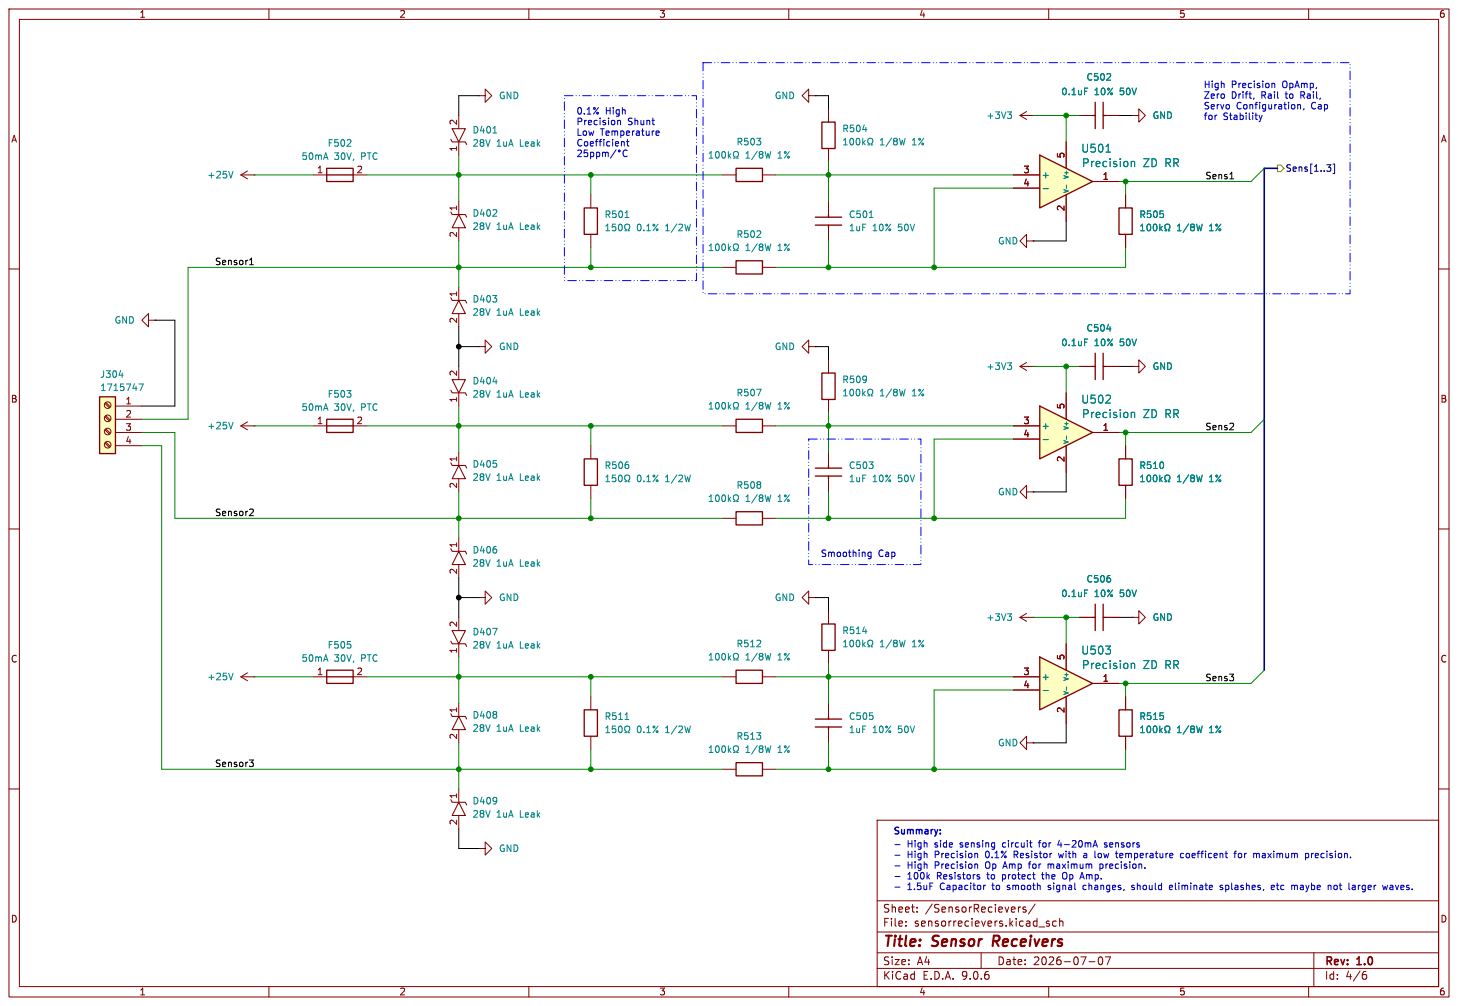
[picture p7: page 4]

File: sensorrecievers.kicad_sch Sheet: /SensorRecievers/
Id: 4/6 Title: Sensor Receivers

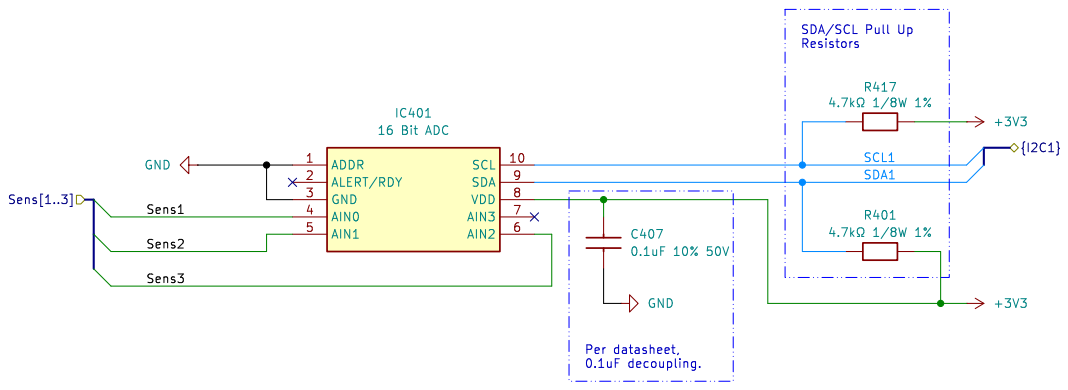
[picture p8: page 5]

SDA/SCL Pull Up Resistors Summary: Per datasheet, 0.1uF decoupling.

Id: 5/6 Title: Analog Digital Converter File: adc.kicad_sch Sheet: /AnalogDigitalConverter/

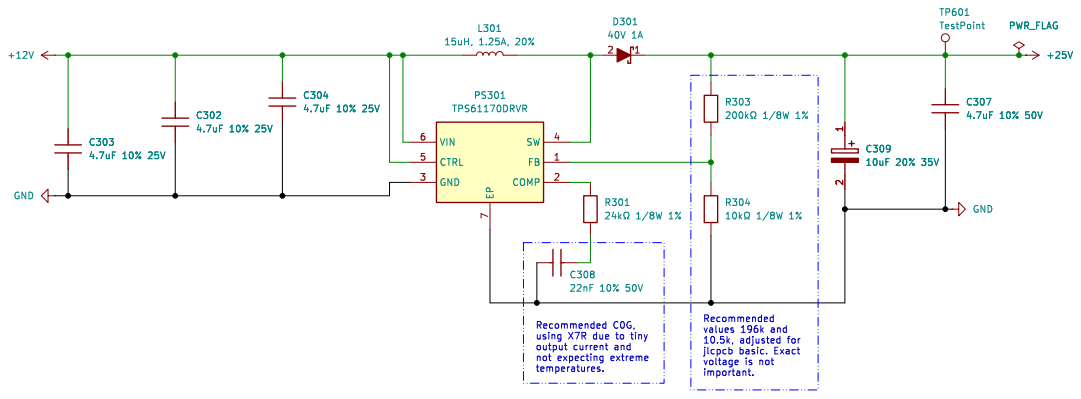
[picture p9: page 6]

values 196k and
jlcpcb basic. Exact voltage is not

Id: 6/6 Title: Sensor Power Conversion

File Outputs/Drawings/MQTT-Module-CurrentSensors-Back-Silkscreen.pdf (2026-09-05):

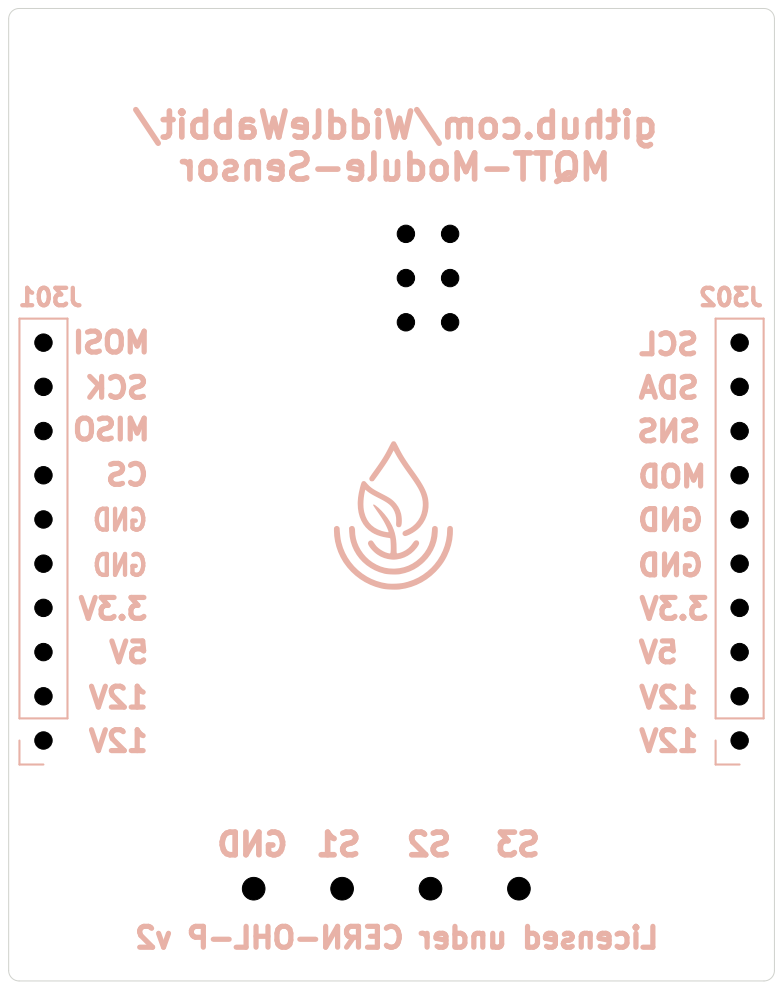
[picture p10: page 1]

Id: 1/1 Title: File: MQTT-Module-CurrentSensors.kicad_pcb Sheet: MOD

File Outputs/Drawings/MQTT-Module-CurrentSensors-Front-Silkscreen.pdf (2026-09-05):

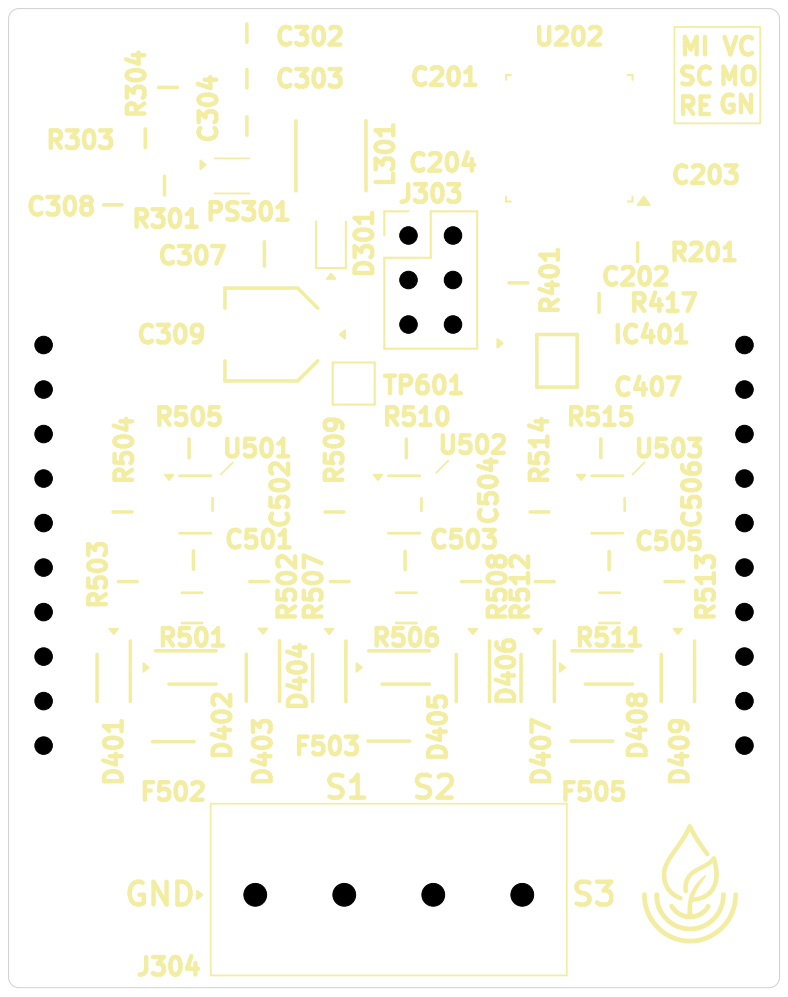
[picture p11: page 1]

Id: 1/1 Title: File: MQTT-Module-CurrentSensors.kicad_pcb Sheet: GND

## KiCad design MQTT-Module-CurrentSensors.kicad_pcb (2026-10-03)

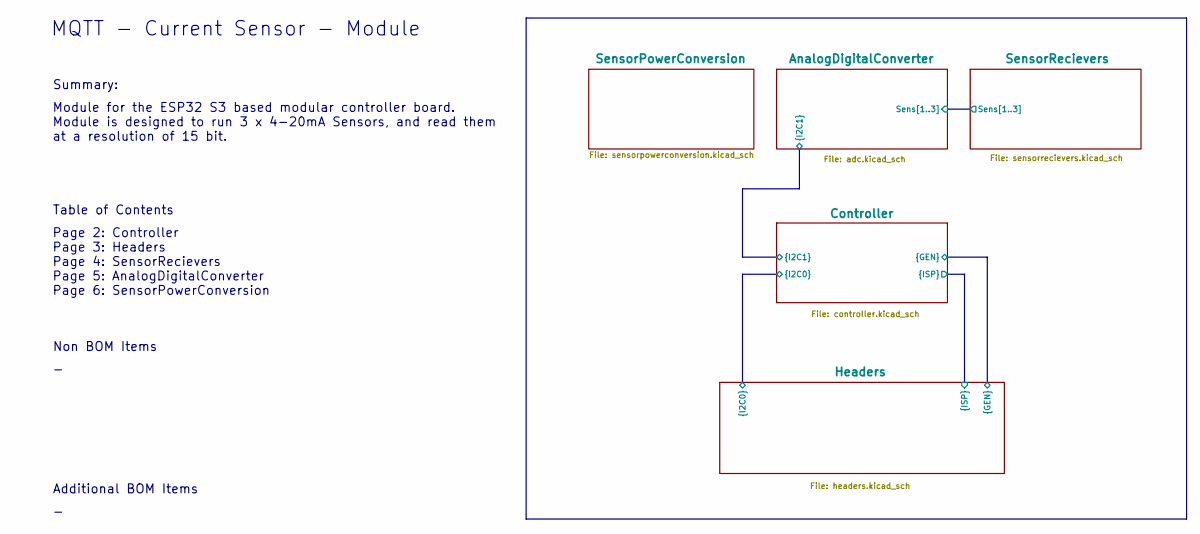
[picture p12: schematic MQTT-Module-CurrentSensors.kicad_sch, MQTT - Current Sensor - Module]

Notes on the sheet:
MQTT - Current Sensor - Module
Additional BOM Items
Summary:
Non BOM Items
Page 2: Controller Page 3: Headers Page 4: SensorRecievers Page 5: AnalogDigitalConverter Page 6: SensorPowerConversion
Table of Contents
Module for the ESP32 S3 based modular controller board. Module is designed to run 3 x 4-20mA Sensors, and read them at a resolution of 15 bit.

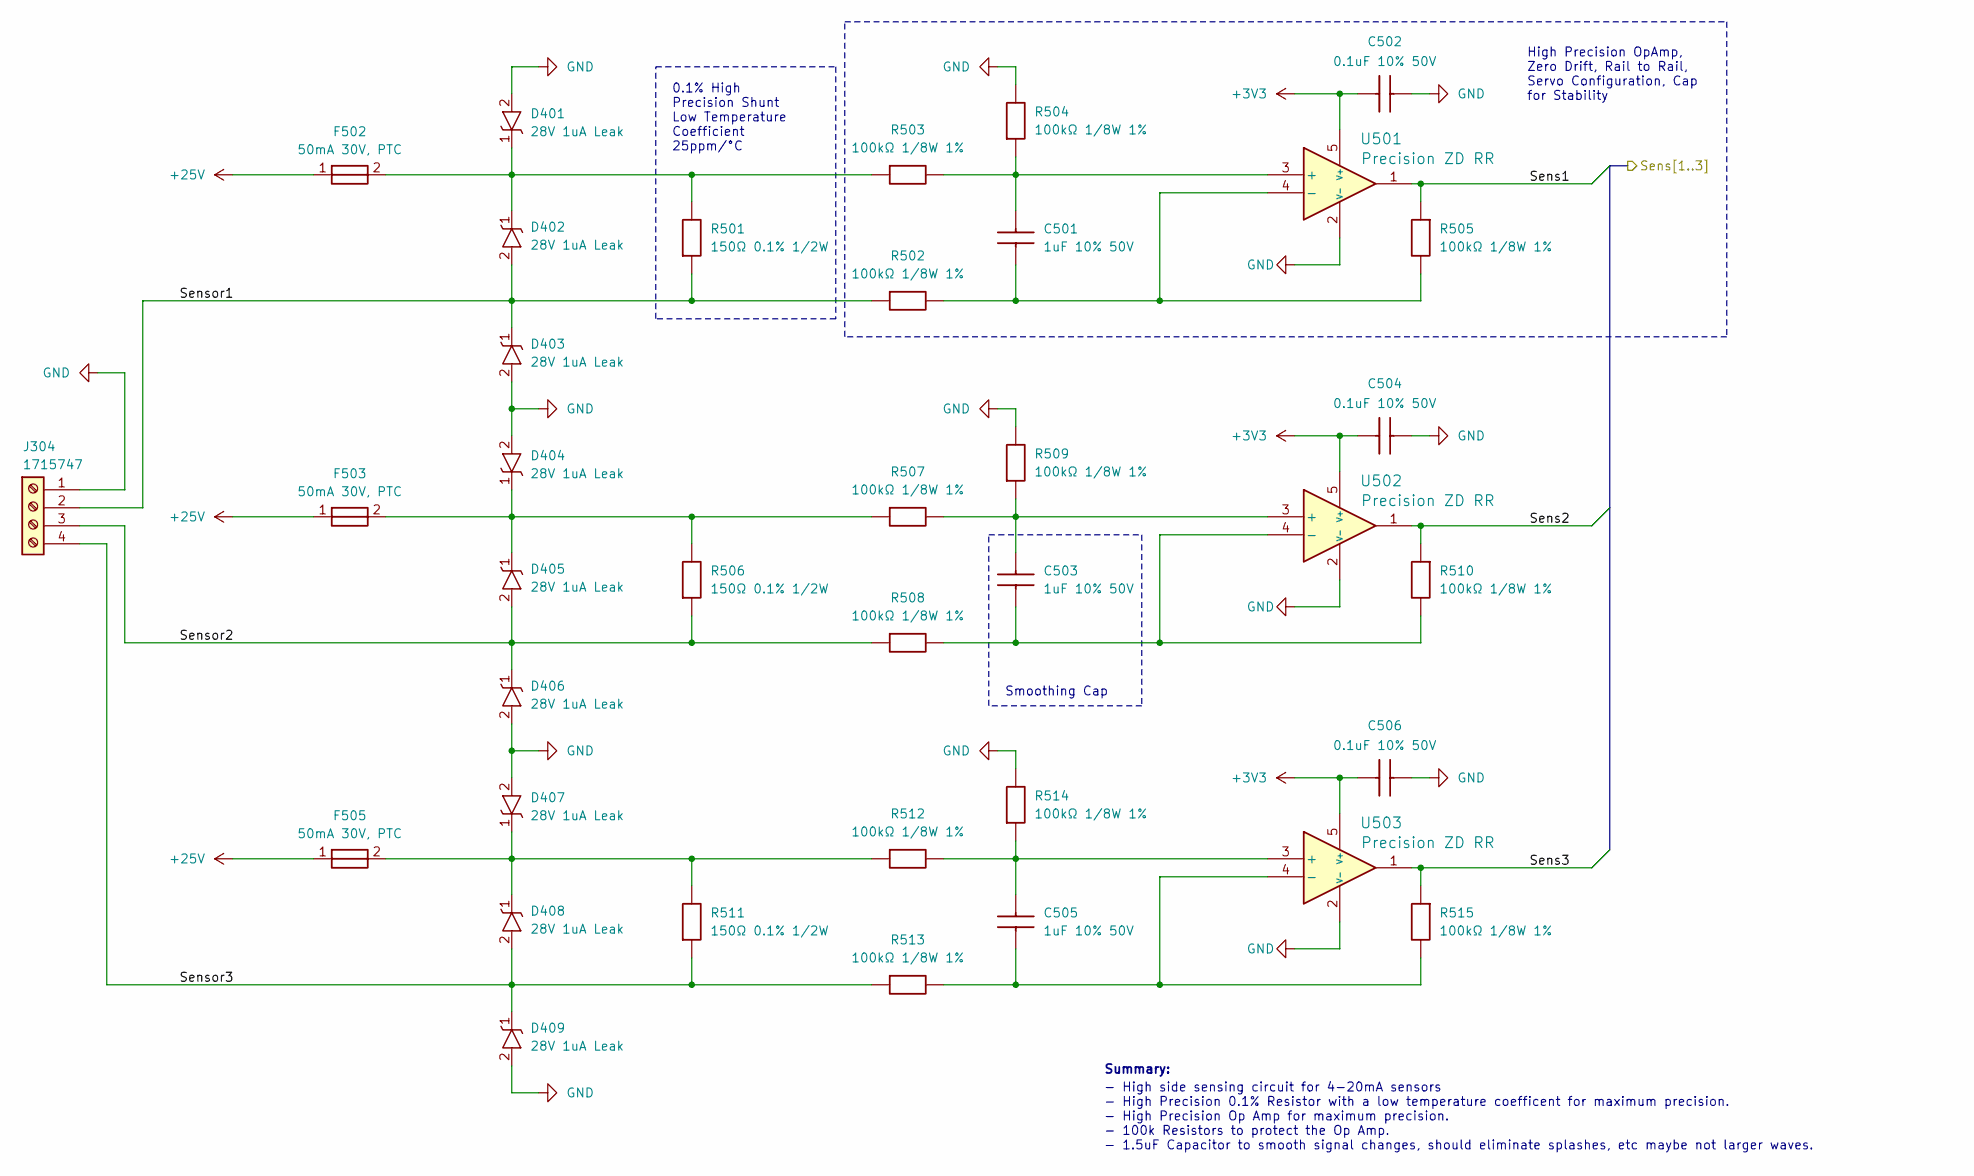
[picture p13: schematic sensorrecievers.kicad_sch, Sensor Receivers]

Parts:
C501, C503, C505: 1uF 10% 50V; CAPC2012X135N; Mouser Part Number 187-CL21B105KBFNNNE
C502, C504, C506: 0.1uF 10% 50V; CAPC1608X90N; Mouser Part Number 603-CC603KRX7R9BB104
D401, D402, D403, D404, D405, D406, D407, D408, D409: 28V 1uA Leak; SODFL3619X98N; Manufacturer Part No SMF28A; JLCPCB Part # C720061
F502, F503, F505: 50mA 30V, PTC; FUSC3226X110N; Mouser Part Number 652-MF-USMF005-2
J304: 1715747; Mouser Part Number 651-1715747
R501, R506, R511: 150Ω 0.1% 1/2W; RESC3216X71N; Mouser Part Number 71-TNPW1206150RBEEA
R502, R503, R504, R505, R507, R508, R509, R510, R512, R513, R514, R515: 100kΩ 1/8W 1%; RESC2013X65N; Mouser Part Number 303-0805W8F1003T5E
U501, U502, U503: Precision ZD RR; S5TSOT23-5-A_TPK; Manufacturer Part No TP5551-TR; JLCPCB Part # C2759987

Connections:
+3V3: C502.1, C504.1, C506.1, U501.5 (V+), U502.5 (V+), U503.5 (V+); also elsewhere on the board
+25V: F502.1, F503.1, F505.1; also elsewhere on the board
/AnalogDigitalConverter/Sens1: R505.1, U501.1; also elsewhere on the board
/AnalogDigitalConverter/Sens2: R510.1, U502.1; also elsewhere on the board
/AnalogDigitalConverter/Sens3: R515.1, U503.1; also elsewhere on the board
/SensorRecievers/Sensor1: D402.2 (A2), D403.1 (A1), J304.2, R501.1, R502.1
/SensorRecievers/Sensor2: D405.2 (A2), D406.1 (A1), J304.3, R506.1, R508.1
/SensorRecievers/Sensor3: D408.2 (A2), D409.1 (A1), J304.4, R511.1, R513.1
GND: C502.2, C504.2, C506.2, D401.2 (A2), D403.2 (A2), D404.2 (A2), D406.2 (A2), D407.2 (A2), D409.2 (A2), J304.1, R504.2, R509.2, R514.2, U501.2 (V-), U502.2 (V-), U503.2 (V-); also elsewhere on the board
unnamed: D401.1 (A1), D402.1 (A1), F502.2, R501.2, R503.1
unnamed: D404.1 (A1), D405.1 (A1), F503.2, R506.2, R507.1
unnamed: D407.1 (A1), D408.1 (A1), F505.2, R511.2, R512.1
unnamed: C501.2, R503.2, R504.1, U501.3 (+)
unnamed: C501.1, R502.2, R505.2, U501.4 (-)
unnamed: C503.2, R507.2, R509.1, U502.3 (+)
unnamed: C503.1, R508.2, R510.2, U502.4 (-)
unnamed: C505.2, R512.2, R514.1, U503.3 (+)
unnamed: C505.1, R513.2, R515.2, U503.4 (-)

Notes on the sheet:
High Precision OpAmp, Zero Drift, Rail to Rail, Servo Configuration, Cap for Stability
0.1% High Precision Shunt Low Temperature Coefficient 25ppm/°C
Smoothing Cap
- High side sensing circuit for 4-20mA sensors - High Precision 0.1% Resistor with a low temperature coefficent for maximum precision. - High Precision Op Amp for maximum precision. - 100k Resistors to protect the Op Amp. - 1.5uF Capacitor to smooth signal changes, should eliminate splashes, etc ma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
Summary:

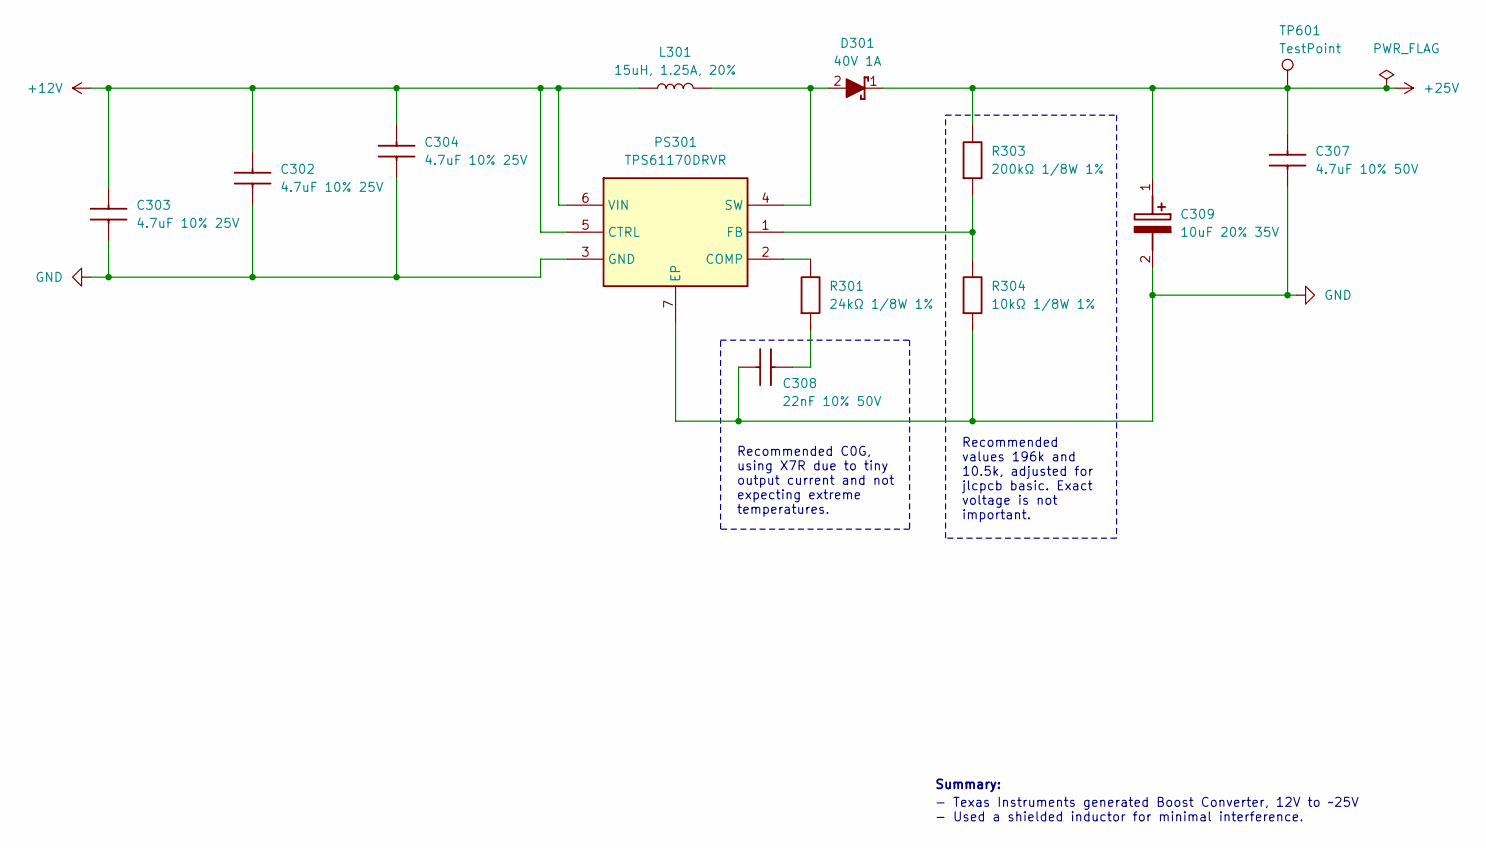
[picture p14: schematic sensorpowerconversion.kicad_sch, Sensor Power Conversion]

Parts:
C302, C303, C304: 4.7uF 10% 25V; CAPC2012X140N; Mouser Part Number 187-CL21A475KAQNNNE
C307: 4.7uF 10% 50V; CAPC3216X180N; Manufacturer Part No 1206B475K500NT; JLCPCB Part # C29823
C308: 22nF 10% 50V; CAPC2012X75N; Manufacturer Part No CL21B223KBANNNC; JLCPCB Part # C1729
C309: 10uF 20% 35V; EEE0GA101SR; Mouser Part Number 667-EEE-FK1V100R
D301: 40V 1A; D_SOD-323F; Manufacturer Part No 1N5819WS; JLCPCB Part # C191023
L301: 15uH, 1.25A, 20%; INDM4040X190N; Mouser Part Number 70-IFSC1515AHER150M0
PS301: TPS61170DRVR; SON65P200X200X80-7N; Mouser Part Number 595-TPS61170DRVR
R301: 24kΩ 1/8W 1%; RESC2013X65N; Manufacturer_Part_Number 0805W8F2402T5E; JLCPCB Part # C17575
R303: 200kΩ 1/8W 1%; RESC2013X65N; Manufacturer Part No 0805W8F2003T5E; JLCPCB Part # C17539
R304: 10kΩ 1/8W 1%; RESC2013X65N; Mouser Part Number 303-0805W8F1002T5E
TP601: TestPoint; TestPoint_Pad_2.0x2.0mm

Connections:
+12V: C302.2, C303.2, C304.2, L301.1, PS301.5 (CTRL), PS301.6 (VIN); also elsewhere on the board
+25V: C307.2, C309.1 (+), D301.1 (K), R303.2, TP601.1; also elsewhere on the board
GND: C302.1, C303.1, C304.1, C307.1, C308.1, C309.2 (-), PS301.3 (GND), PS301.7 (EP), R304.1; also elsewhere on the board
unnamed: C308.2, R301.1
unnamed: D301.2 (A), L301.2, PS301.4 (SW)
unnamed: PS301.2 (COMP), R301.2
unnamed: PS301.1 (FB), R303.1, R304.2

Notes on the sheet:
- Texas Instruments generated Boost Converter, 12V to ~25V - Used a shielded inductor for minimal interference.
Recommended values 196k and 10.5k, adjusted for jlcpcb basic. Exact voltage is not important.
Recommended C0G, using X7R due to tiny output current and not expecting extreme temperatures.
Summary:

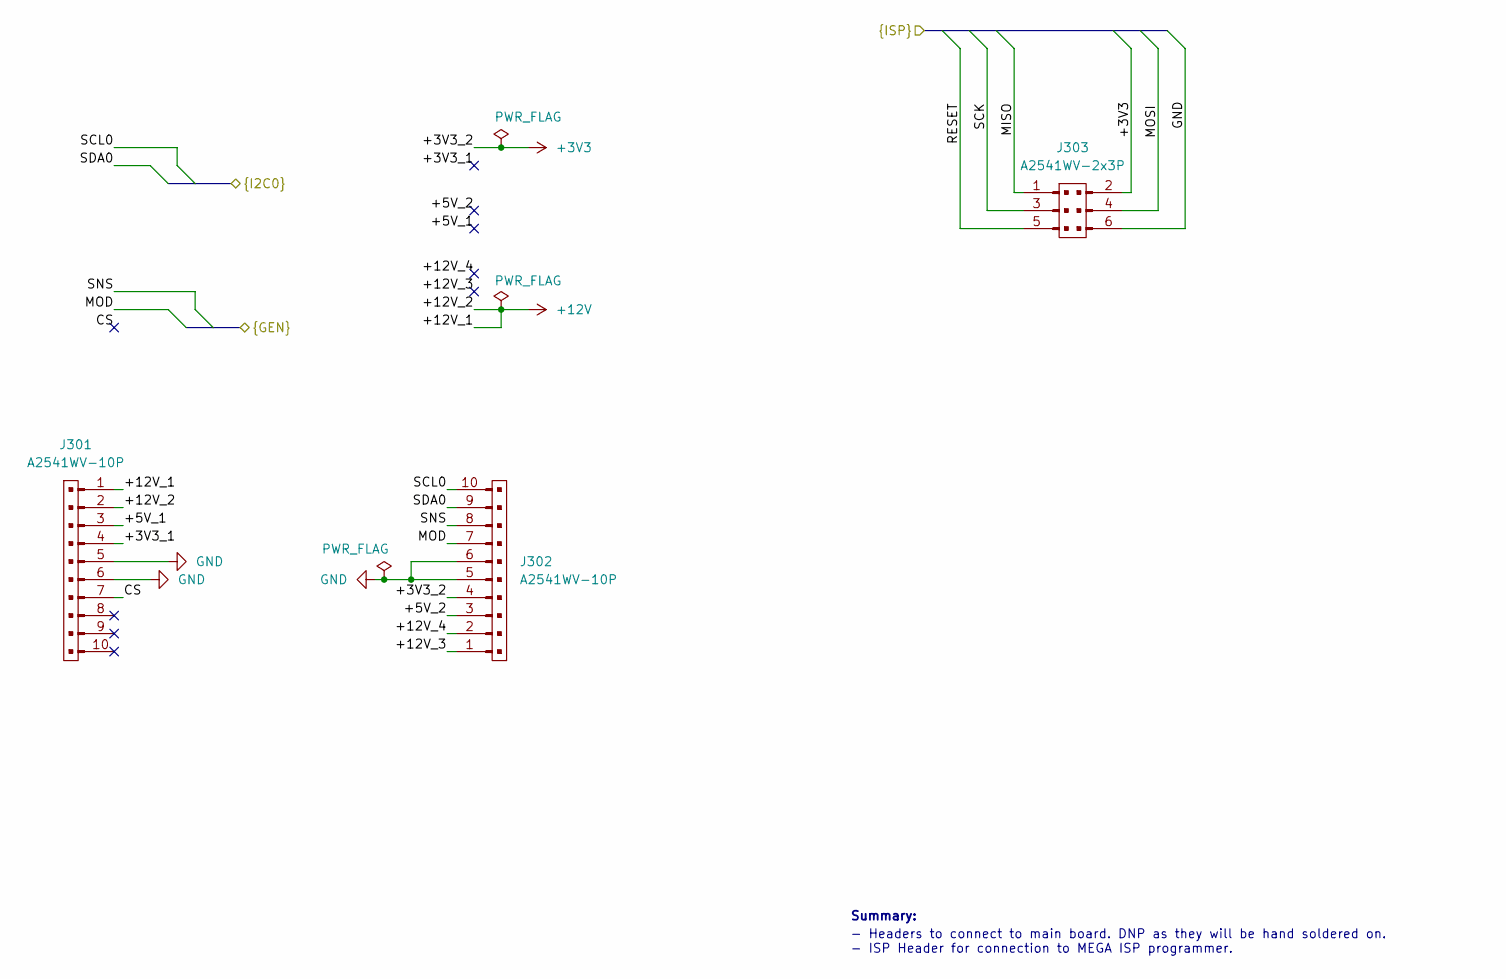
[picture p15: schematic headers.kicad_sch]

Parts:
J301, J302: A2541WV-10P; PinHeader_1x10_P2.54mm_Vertical_Male; Manufacturer Part No A2541WV-10P; JLCPCB Part # C225485
J303: A2541WV-2x3P; PinHeader_2x03_P2.54mm_Vertical_Male; Manufacturer Part No A2541WV-2x3P; JLCPCB Part # C225518

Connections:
+3V3: J302.4, J303.2; also elsewhere on the board
+12V: J301.1, J301.2; also elsewhere on the board
/Controller/MISO: J303.1; also elsewhere on the board
/Controller/MOD: J302.7; also elsewhere on the board
/Controller/MOSI: J303.4; also elsewhere on the board
/Controller/RESET: J303.5; also elsewhere on the board
/Controller/SCK: J303.3; also elsewhere on the board
/Controller/SCL0: J302.10; also elsewhere on the board
/Controller/SDA0: J302.9; also elsewhere on the board
/Controller/SNS: J302.8; also elsewhere on the board
/Headers/+3V3_1: J301.4
/Headers/+5V_1: J301.3
/Headers/+5V_2: J302.3
/Headers/+12V_3: J302.1
/Headers/+12V_4: J302.2
/Headers/CS: J301.7
GND: J301.5, J301.6, J302.5, J302.6, J303.6; also elsewhere on the board

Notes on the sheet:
Summary:
- Headers to connect to main board. DNP as they will be hand soldered on. - ISP Header for connection to MEGA ISP programmer.

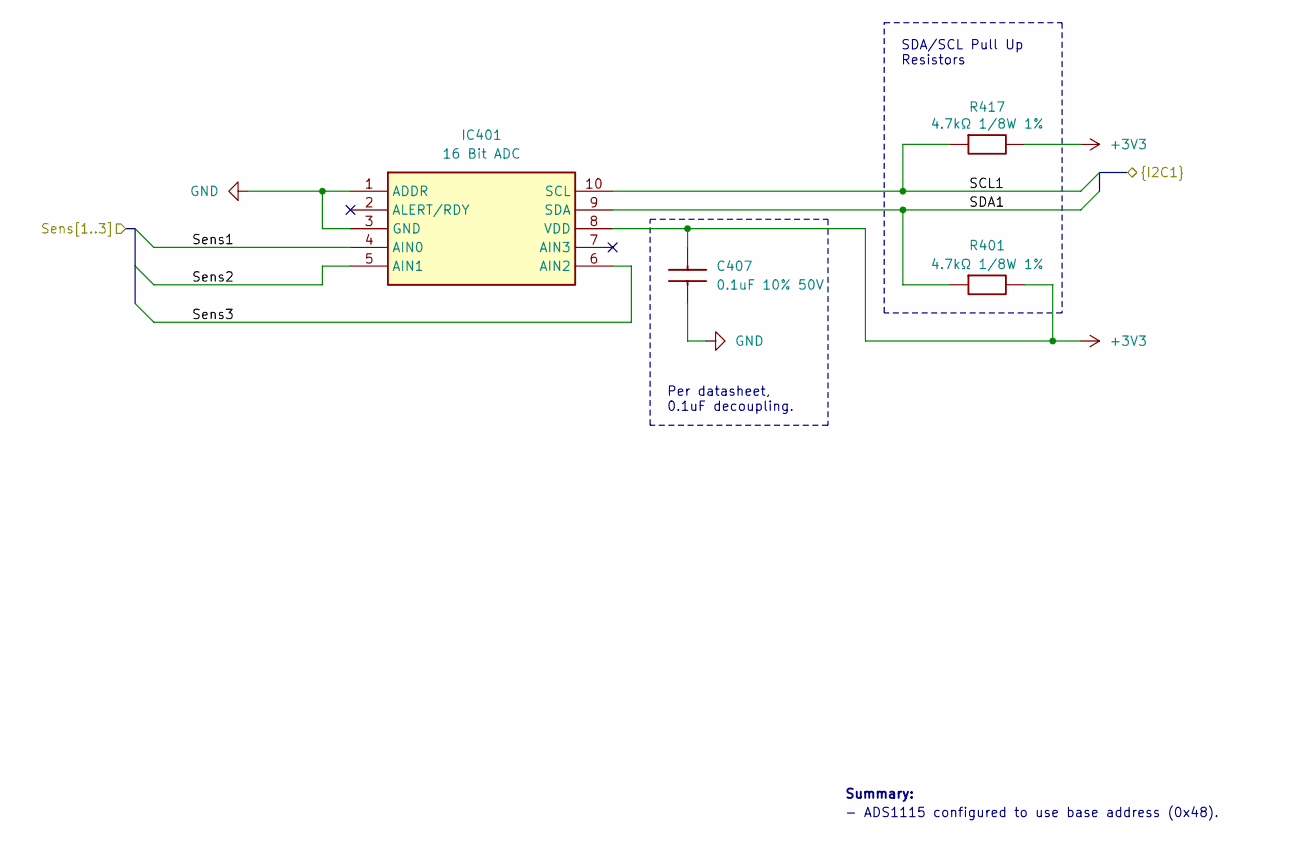
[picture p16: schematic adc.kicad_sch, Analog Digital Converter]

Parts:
C407: 0.1uF 10% 50V; CAPC1608X90N; Mouser Part Number 603-CC603KRX7R9BB104
IC401: 16 Bit ADC; SOP50P490X110-10N; Mouser Part Number 595-ADS1115IDGST
R401, R417: 4.7kΩ 1/8W 1%; RESC2013X65N; Mouser Part Number 303-0805W8F4701T5E

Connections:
+3V3: C407.2, IC401.8 (VDD), R401.2, R417.2; also elsewhere on the board
/AnalogDigitalConverter/SCL1: IC401.10 (SCL), R417.1; also elsewhere on the board
/AnalogDigitalConverter/SDA1: IC401.9 (SDA), R401.1; also elsewhere on the board
/AnalogDigitalConverter/Sens1: IC401.4 (AIN0); also elsewhere on the board
/AnalogDigitalConverter/Sens2: IC401.5 (AIN1); also elsewhere on the board
/AnalogDigitalConverter/Sens3: IC401.6 (AIN2); also elsewhere on the board
GND: C407.1, IC401.1 (ADDR), IC401.3 (GND); also elsewhere on the board

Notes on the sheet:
SDA/SCL Pull Up Resistors
- ADS1115 configured to use base address (0x48).
Per datasheet, 0.1uF decoupling.
Summary:

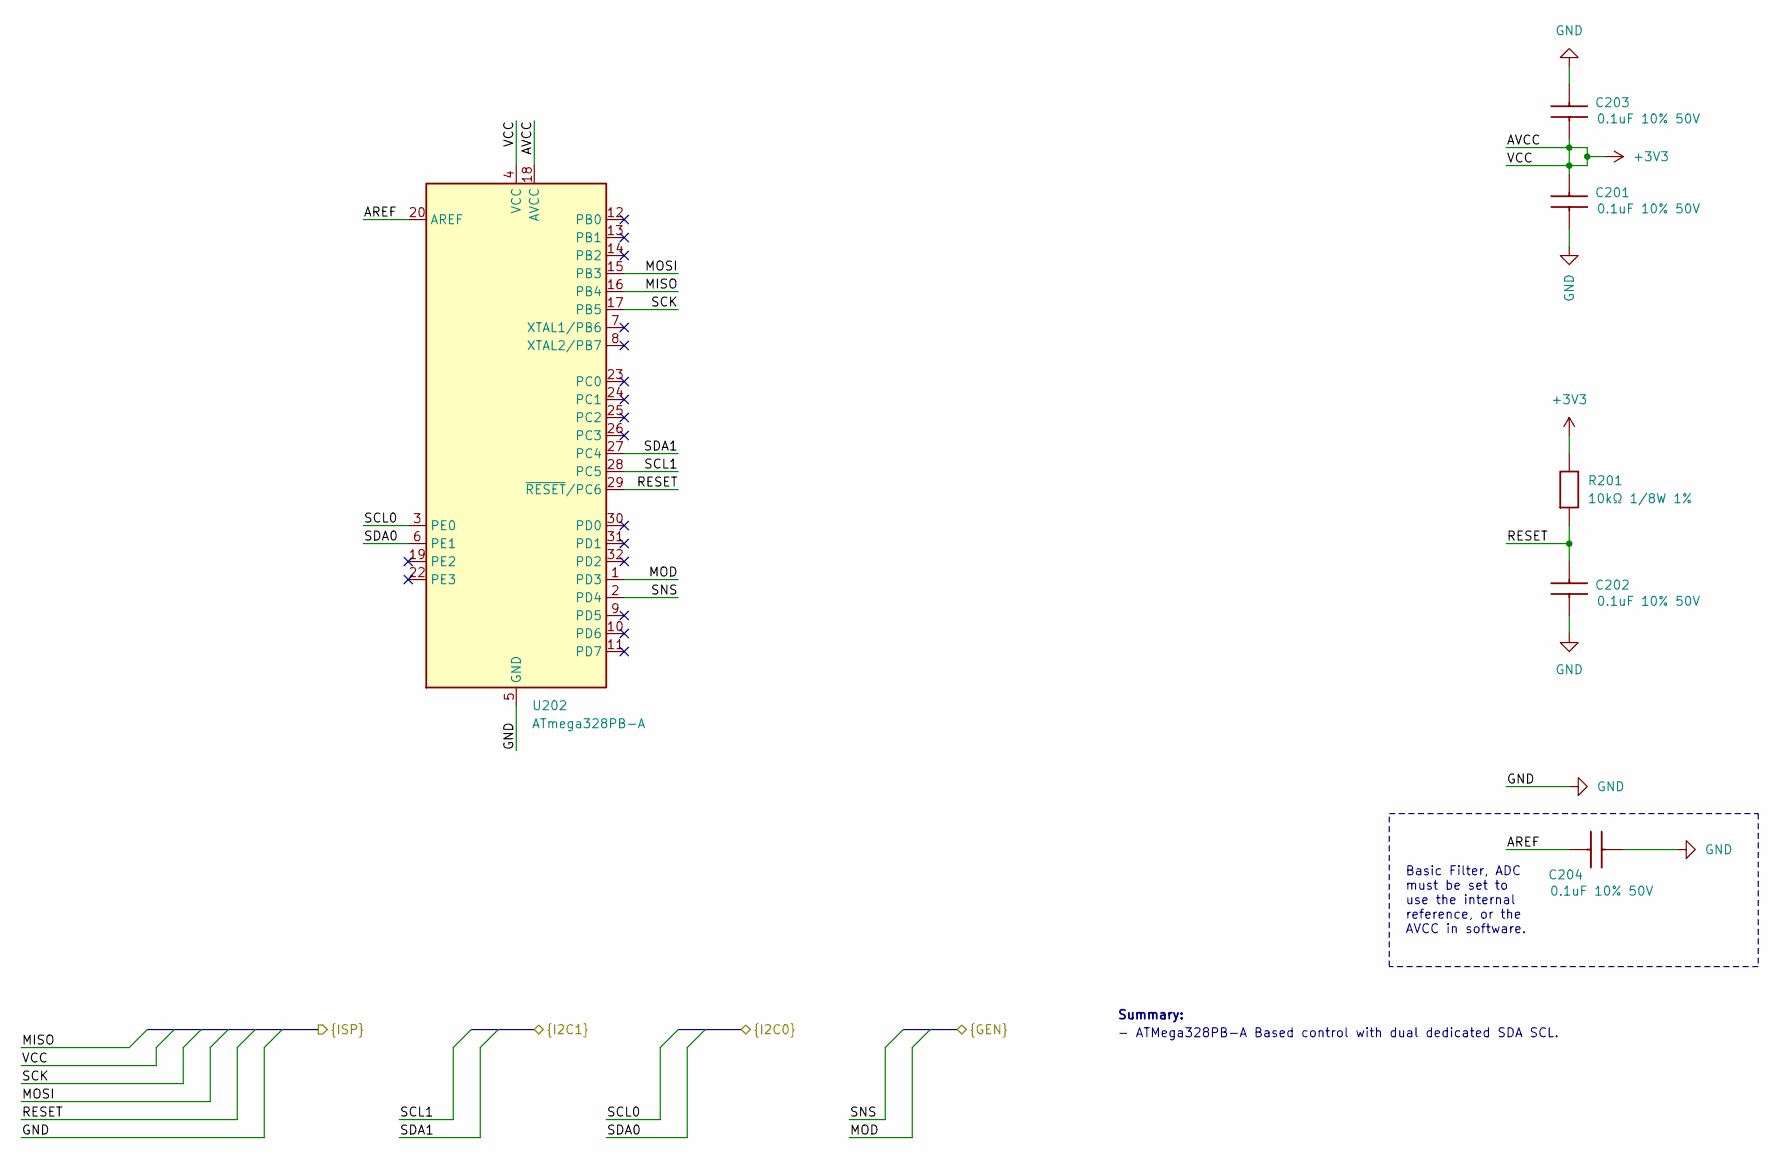
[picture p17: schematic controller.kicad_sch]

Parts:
C201, C202, C203, C204: 0.1uF 10% 50V; CAPC1608X90N; Mouser Part Number 603-CC603KRX7R9BB104
R201: 10kΩ 1/8W 1%; RESC2013X65N; Mouser Part Number 303-0805W8F1002T5E
U202: ATmega328PB-A; TQFP-32_7x7mm_P0.8mm; Manufacturer Part No ATMEGA328PB-AU; JLCPCB Part # C132230

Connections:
+3V3: C201.2, C203.1, R201.2, U202.4 (VCC), U202.18 (AVCC); also elsewhere on the board
/AnalogDigitalConverter/SCL1: U202.28 (PC5); also elsewhere on the board
/AnalogDigitalConverter/SDA1: U202.27 (PC4); also elsewhere on the board
/Controller/AREF: C204.1, U202.20 (AREF)
/Controller/MISO: U202.16 (PB4); also elsewhere on the board
/Controller/MOD: U202.1 (PD3); also elsewhere on the board
/Controller/MOSI: U202.15 (PB3); also elsewhere on the board
/Controller/RESET: C202.1, R201.1, U202.29 (~RESET/PC6); also elsewhere on the board
/Controller/SCK: U202.17 (PB5); also elsewhere on the board
/Controller/SCL0: U202.3 (PE0); also elsewhere on the board
/Controller/SDA0: U202.6 (PE1); also elsewhere on the board
/Controller/SNS: U202.2 (PD4); also elsewhere on the board
GND: C201.1, C202.2, C203.2, C204.2, U202.5 (GND), U202.21 (GND); also elsewhere on the board

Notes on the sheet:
Basic Filter, ADC must be set to use the internal reference, or the AVCC in software.
- ATMega328PB-A Based control with dual dedicated SDA SCL.
Summary:

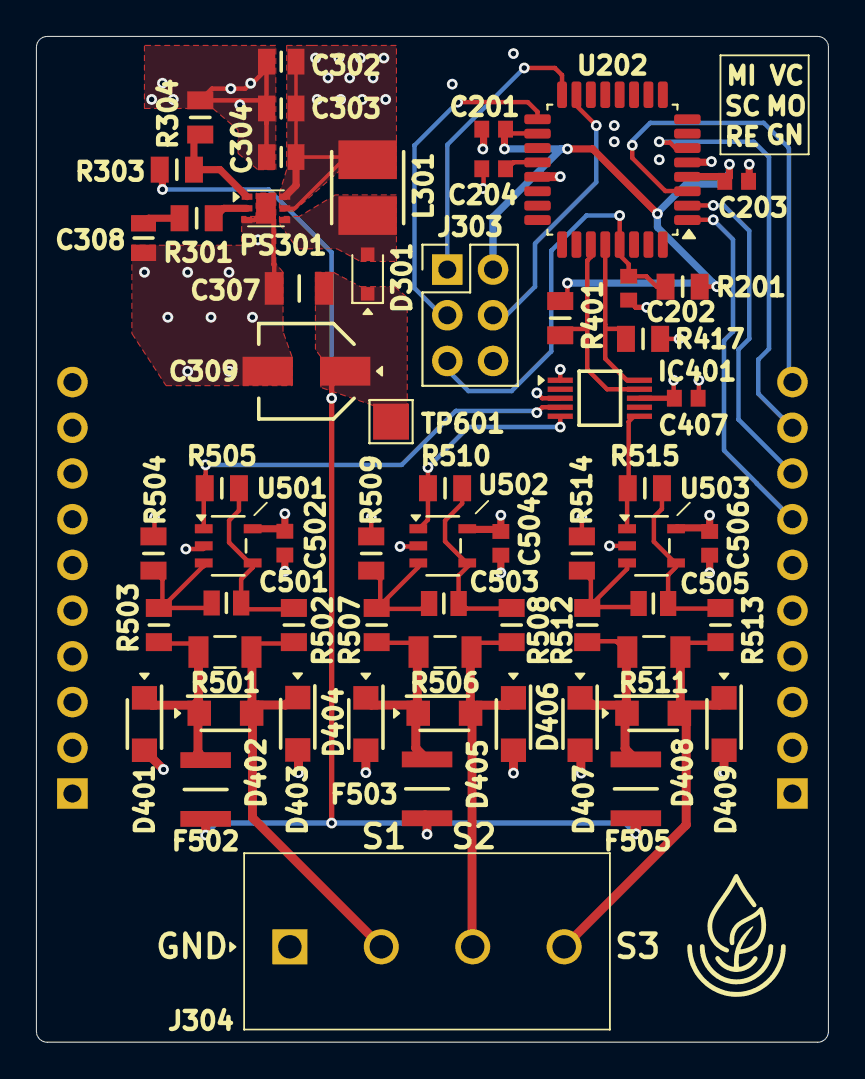
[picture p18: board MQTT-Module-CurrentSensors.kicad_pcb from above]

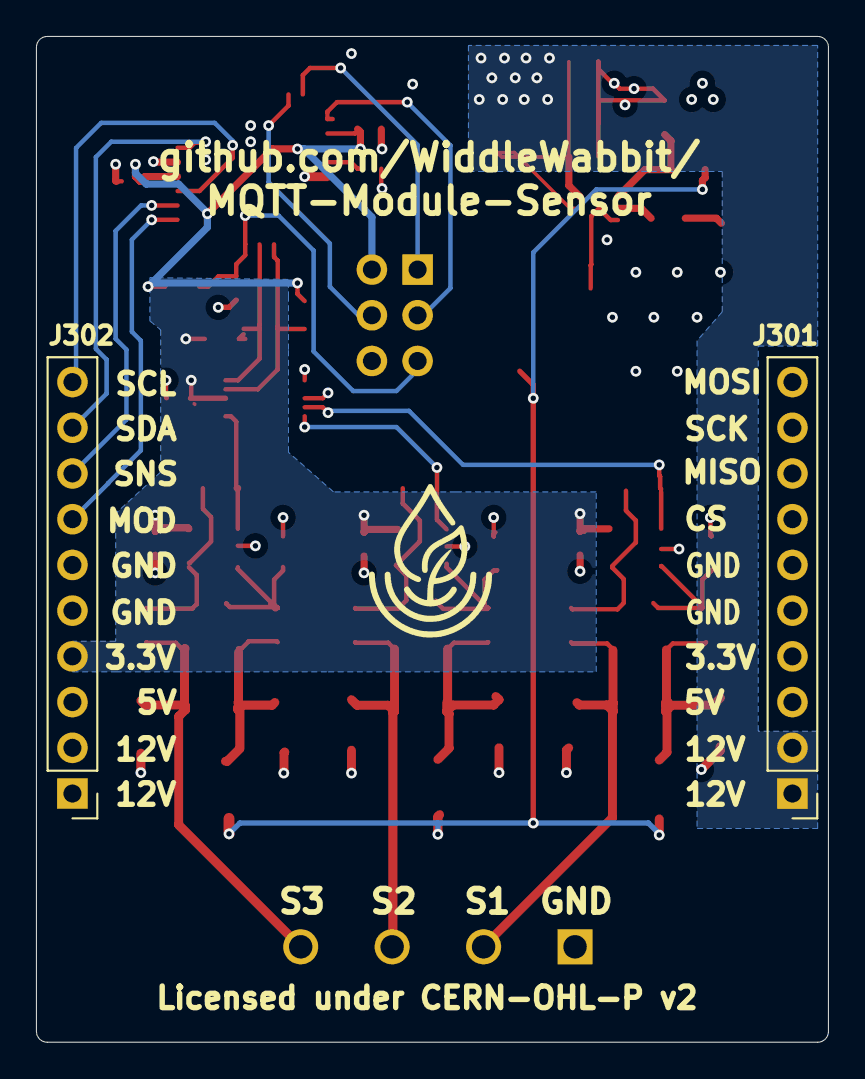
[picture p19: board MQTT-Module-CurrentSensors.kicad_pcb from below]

Board: 4 copper layers, 44.0 x 55.9 mm, 63 parts (2 on the bottom side), 34 nets.

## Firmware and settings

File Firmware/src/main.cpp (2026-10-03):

#include <Arduino.h>

#include "AvrAds1115.h"
#include "AvrTwi1Slave.h"
#include "ModuleLink.h"
#include "ModuleProtocol.h"
#include "SensorInputs.h"


// ========== Board pins ==========

// Motherboard bus is schematic I2C0. It is the chip's TWI1 peripheral:
// PE0 is SCL and PE1 is SDA. Wire1 owns these pins in hardware.
const uint8_t SCL_PIN = 23;
const uint8_t SDA_PIN = 24;
const uint8_t MOD_PIN = 3;
const uint8_t SNS_PIN = 4;

// ADC bus is schematic I2C1. It is the chip's TWI0 peripheral.
// PC4 is SDA and PC5 is SCL. Wire owns these pins in hardware.
const uint8_t ADC_SDA_PIN = 18;
const uint8_t ADC_SCL_PIN = 19;

static_assert(SCL_PIN == 23, "PE0 is motherboard SCL.");
static_assert(SDA_PIN == 24, "PE1 is motherboard SDA.");
static_assert(MOD_PIN == 3, "PD3 is MOD.");
static_assert(SNS_PIN == 4, "PD4 is SNS.");
static_assert(ADC_SDA_PIN == 18, "PC4 is ADC SDA.");
static_assert(ADC_SCL_PIN == 19, "PC5 is ADC SCL.");


// ========== Product settings ==========

const uint16_t MODULE_TYPE = module_protocol::kTypeSensorModule;
const uint16_t FIRMWARE_VERSION = 1;

// ADDR is strapped to GND on this board.
const uint8_t ADS1115_ADDRESS = 0x48;
const uint8_t SENSOR_COUNT = 3;

// 2400 counts is 0.300 V at GAIN_ONE (125 uV per count): 2 mA through
// the 150 ohm shunt. A live 4 mA loop sits above this. An open input does not.
const int16_t SENSOR_CONNECTED_MIN_COUNTS = 2400;


// ========== Modules ==========

AvrTwi1Slave moduleSlave;
AvrAds1115 ads(ADS1115_ADDRESS, AvrAds1115::kGainOne,
               AvrAds1115::kRate860Sps);
SensorInputs sensorInputs(ads, SENSOR_COUNT, SENSOR_CONNECTED_MIN_COUNTS);
ModuleLink moduleLink(moduleSlave, sensorInputs, MODULE_TYPE, FIRMWARE_VERSION);


// ========== Application ==========

/**
 * Drives SNS low so the motherboard sees this module seated, and holds
 * MOD as an input with pull-up. The slave stays off until MOD is low.
 *
 * @return Nothing.
 */
void setup()
{
  pinMode(SNS_PIN, OUTPUT);
  digitalWrite(SNS_PIN, LOW);
  pinMode(MOD_PIN, INPUT_PULLUP);
}

/**
 * Advances the ADS1115 scan one step, then gates the unconfigured
 * address on MOD. A low MOD enables 0x0A. After SET_ADDRESS the link
 * keeps that address. This loop does not block, so the host's 5 ms
 * MOD gate is met.
 *
 * @return Nothing.
 */
void loop()
{
  sensorInputs.update();
  const bool modIsLow = digitalRead(MOD_PIN) == LOW;
  moduleLink.update(modIsLow);
}

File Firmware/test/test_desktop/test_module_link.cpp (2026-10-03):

#include <unity.h>

#include "ModuleLink.h"
#include "ModuleProtocol.h"
#include "fakes/FakeAds1115.h"
#include "fakes/FakeModuleSlavePort.h"

namespace
{

constexpr uint16_t kTestType = module_protocol::kTypeSensorModule;
constexpr uint16_t kTestFirmwareVersion = 1;
constexpr int16_t kConnectedMinCounts = 2400;

/**
 * One link, its slave fake, and a sensor cache. The default count is
 * 0 so a protocol test does not depend on a conversion.
 */
struct Board
{
  FakeAds1115 adc;
  SensorInputs sensors;
  FakeModuleSlavePort port;
  ModuleLink link;

  /**
   * Builds a link around a sensor cache of the given size.
   *
   * @param sensorCount Inputs the cache reports.
   * @param typeId Type id supplied to the link.
   * @param firmwareVersion Firmware version supplied to the link.
   */
  explicit Board(uint8_t sensorCount = 0,
                 uint16_t typeId = kTestType,
                 uint16_t firmwareVersion = kTestFirmwareVersion)
    : sensors(adc, sensorCount, kConnectedMinCounts),
      link(port, sensors, typeId, firmwareVersion)
  {
  }
};

/**
 * Builds one request frame, including its CRC.
 *
 * @param command Command byte.
 * @param payload Payload bytes, or nullptr when payloadLen is 0.
 * @param payloadLen Payload length.
 * @param out Destination. Must hold payloadLen + 3 bytes.
 * @return On-wire size, including the CRC byte.
 */
size_t buildFrame(uint8_t command, const uint8_t* payload, uint8_t payloadLen,
                  uint8_t* out)
{
  const uint8_t lengthField = static_cast<uint8_t>(2 + payloadLen);
  out[0] = lengthField;
  out[1] = command;
  for (uint8_t index = 0; index < payloadLen; ++index)
  {
    out[2 + index] = payload[index];
  }
  out[lengthField] = module_protocol::crc8Smbus(out, lengthField);
  return static_cast<size_t>(lengthField) + 1U;
}

/**
 * Delivers one CRC-valid command through the fake port.
 *
 * @param port Fake whose handler receives the frame.
 * @param command Command byte.
 * @param payload Payload bytes, or nullptr when payloadLen is 0.
 * @param payloadLen Payload length.
 * @return Nothing.
 */
void writeCommand(FakeModuleSlavePort& port, uint8_t command,
                  const uint8_t* payload, uint8_t payloadLen)
{
  uint8_t frame[module_protocol::kMaxFrameBytes] = {};
  const size_t size = buildFrame(command, payload, payloadLen, frame);
  port.deliver(frame, size);
}

/**
 * Checks a 19-byte padded reply against status and payload.
 *
 * @param port Fake that received setReply.
 * @param status Expected status byte.
 * @param payload Expected payload, or nullptr when payloadLen is 0.
 * @param payloadLen Expected payload length.
 * @return Nothing.
 */
void expectReply(const FakeModuleSlavePort& port, uint8_t status,
                 const uint8_t* payload, uint8_t payloadLen)
{
  uint8_t expected[module_protocol::kMaxFrameBytes];
  for (uint8_t index = 0; index < module_protocol::kMaxFrameBytes; ++index)
  {
    expected[index] = 0xFF;
  }
  const uint8_t lengthField = static_cast<uint8_t>(2 + payloadLen);
  expected[0] = lengthField;
  expected[1] = status;
  for (uint8_t index = 0; index < payloadLen; ++index)
  {
    expected[2 + index] = payload[index];
  }
  expected[lengthField] = module_protocol::crc8Smbus(expected, lengthField);
  TEST_ASSERT_EQUAL(module_protocol::kMaxFrameBytes, port.replyLength);
  TEST_ASSERT_EQUAL_UINT8_ARRAY(expected, port.reply,
                                module_protocol::kMaxFrameBytes);
}

/**
 * Fills an identity payload from the values passed to the link.
 *
 * @param typeId Type id supplied at construction.
 * @param firmwareVersion Firmware version supplied at construction.
 * @param out Destination. Must hold kIdentityPayloadLen bytes.
 * @return Nothing.
 */
void fillIdentity(uint16_t typeId, uint16_t firmwareVersion, uint8_t* out)
{
  out[0] = static_cast<uint8_t>(typeId >> 8);
  out[1] = static_cast<uint8_t>(typeId & 0xFF);
  out[2] = module_protocol::kProtocolVersion;
  out[3] = static_cast<uint8_t>(firmwareVersion >> 8);
  out[4] = static_cast<uint8_t>(firmwareVersion & 0xFF);
}

/**
 * Fills a GET_SENSOR_READING payload.
 *
 * @param index Sensor index echoed in the payload.
 * @param connected Connected flag, 0 or 1.
 * @param value Raw counts.
 * @param out Destination. Must hold kSensorReadingPayloadLen bytes.
 * @return Nothing.
 */
void fillReading(uint8_t index, uint8_t connected, int32_t value, uint8_t* out)
{
  out[0] = index;
  out[1] = connected;
  module_protocol::writeInt32Be(out + 2, value);
}

/**
 * Runs the scan until index has a sample. Fails if that does not
 * happen within a full three-channel cycle.
 *
 * @param board Link fixture whose ADC fake is scripted.
 * @param index Input to wait for.
 * @param counts Value the fake returns for that input.
 * @return Nothing.
 */
void capture(Board& board, uint8_t index, int16_t counts)
{
  board.adc.counts[index] = counts;
  board.adc.ready = true;
  for (uint8_t step = 0; step < 16 && !board.sensors.hasSample(index); ++step)
  {
    board.sensors.update();
  }
  TEST_ASSERT_TRUE(board.sensors.hasSample(index));
}

}

/**
 * Unity setup hook. Each test builds its own link.
 *
 * @return Nothing.
 */
void setUp()
{
}

/**
 * Unity teardown hook.
 *
 * @return Nothing.
 */
void tearDown()
{
}

/**
 * MOD high at boot leaves the slave disabled.
 *
 * @return Nothing.
 */
void testBootWithModHighLeavesSlaveDisabled()
{
  Board board;

  board.link.update(false);

  TEST_ASSERT_FALSE(board.port.enabled);
  TEST_ASSERT_EQUAL(0, board.port.enableCount);
  TEST_ASSERT_EQUAL(0, board.port.disableCount);
  TEST_ASSERT_EQUAL(0, board.port.setAddressCount);
}

/**
 * MOD low enables 0x0A once. MOD high before assignment disables it.
 *
 * @return Nothing.
 */
void testModLowEnablesUnconfiguredAddressAndModHighDisables()
{
  Board board;

  board.link.update(true);
  board.link.update(true);

  TEST_ASSERT_TRUE(board.port.enabled);
  TEST_ASSERT_EQUAL(1, board.port.enableCount);
  TEST_ASSERT_EQUAL(module_protocol::kUnconfiguredAddress,
                    board.port.lastEnabledAddress);
  TEST_ASSERT_EQUAL(0, board.port.setAddressCount);

  board.link.update(false);
  board.link.update(false);

  TEST_ASSERT_FALSE(board.port.enabled);
  TEST_ASSERT_EQUAL(1, board.port.disableCount);
  TEST_ASSERT_EQUAL(0, board.port.setAddressCount);
}

/**
 * PING returns status Ok, an empty payload, a valid CRC, and 0xFF pad.
 *
 * @return Nothing.
 */
void testPingReplyIsOkAndPadded()
{
  Board board;
  board.link.update(true);

  writeCommand(board.port, module_protocol::kCmdPing, nullptr, 0);

  expectReply(board.port, module_protocol::kStatusOk, nullptr, 0);
  TEST_ASSERT_EQUAL(0, board.port.setAddressCount);
}
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

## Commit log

2026-07-08 Added License to Board
    [MQTT-Module-CurrentSensors.kicad_pcb]
2026-07-09 Add README for MQTT Module - Current Sensors
    Added detailed documentation for the MQTT Module that supports current sensors, including features, architecture, power requirements, sensor interface, protection mechanisms, pinout, setup, and licen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
2026-07-09 Update to board.
    [MQTT-Module-CurrentSensors.kicad_pcb]
2026-07-09 Removed one PTC per sensor as it shouldn't be required. Adjusted routing to star pattern.
    [MQTT-Module-CurrentSensors.kicad_pcb, sensorrecievers.kicad_sch]
2026-07-10 Updated trace widths and routing. Improved SDA/SCL lines.
    [MQTT-Module-CurrentSensors.kicad_pcb]
2026-08-04 Updated the diodes to fix issue. Now running 28V diodes for protection of sensing circuit.
    [MQTT-Module-CurrentSensors.kicad_pcb, sensorrecievers.kicad_sch]
2026-08-04 Add testing status note to README
    Added a note indicating that the module is currently in testing.
2026-08-08 Redid the layout to shrink the board. Updated the silkscreen and updated the footprints to better reflect polarities and support a fab pdf.
    [MQTT-Module-CurrentSensors.kicad_pcb, headers.kicad_sch]
2026-08-08 Fixed silkscreen text width
    [BOM.csv, JLC_BOM.csv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]
2026-08-08 Interactive BOM added. Updated Mega Symbol. Updated symbols in schematic. Generated production files.
    [BOM.csv, JLC_BOM.csv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]
2026-08-08 Updated Jobset, It now generates the JLCPCB specific files itself using scripts, images, reanmes the files accordingly etc.
    [BOM.csv, JLCPCB_BOM.csv, JLC_BOM.csv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]
2026-08-08 Removed overflow on mask of ATMEGA. Reconnected traces, ran RRC checks, updated resolution of generated renders to 4k.
    [MQTT-Module-CurrentSensors-B_Cu.gbl, MQTT-Module-CurrentSensors-B_Mask.gbs, MQTT-Module-CurrentSensors-B_Paste.gbp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]
2026-09-05 Updated PCB, increased GND and improved connections on fills.
    [BOM.csv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]
2026-09-30 First version sensor communication added.
2026-10-01 Modified the firmware platformio ini file to use a custom command after debugging the previous setup not working. Platform otherwise seems to mess with the com port preventing the upload. Fuses and u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
2026-10-03 Updated agents.md file.
    [MQTT-Module-CurrentSensors.kicad_pcb]
2026-10-13 Reworked the board, added switching on and off of power to sensors and swapped to a high side dedicated IC for sensing.
2026-11-08 Updated pins and notes in firmware to meet the new board. Turned switches on by default.

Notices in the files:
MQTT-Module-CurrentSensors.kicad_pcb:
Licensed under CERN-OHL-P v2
